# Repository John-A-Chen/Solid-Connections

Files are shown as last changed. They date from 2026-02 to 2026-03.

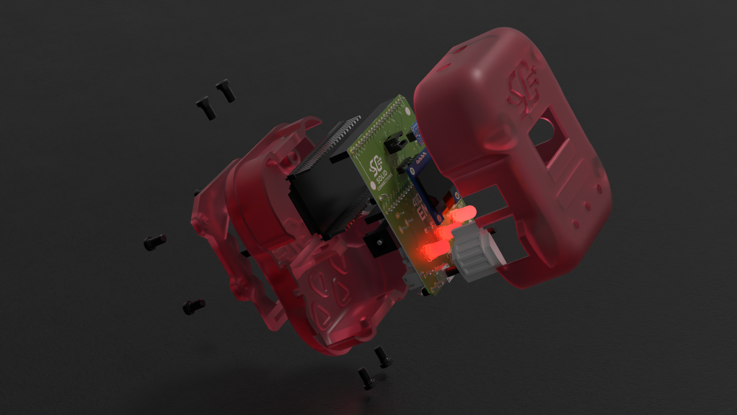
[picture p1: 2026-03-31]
Documentation/Images/render-exploded-assembly-angle-b.png

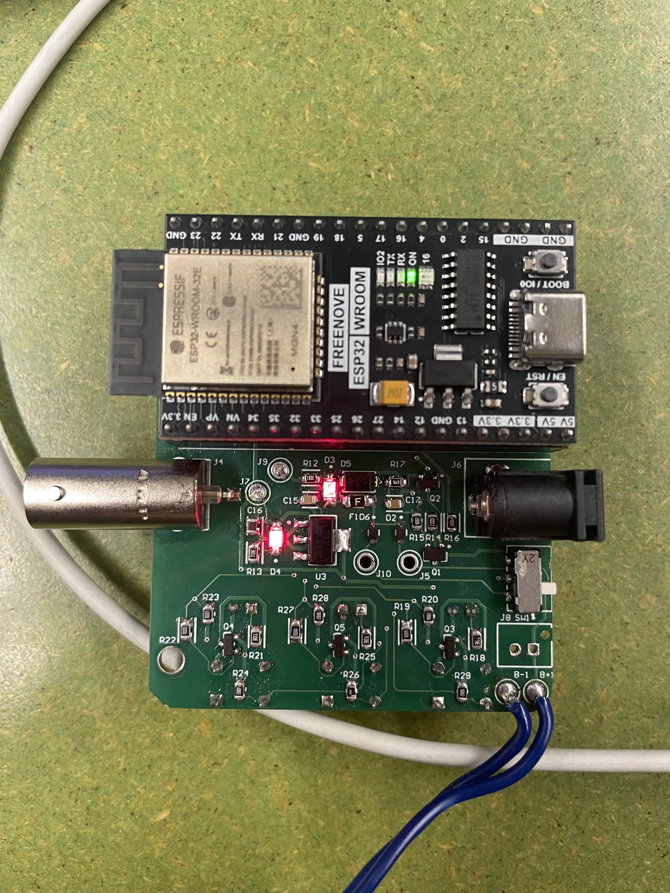
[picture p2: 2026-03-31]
Documentation/Images/photo-pcb-powered-test-setup-01.jpg

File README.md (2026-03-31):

# Solid Connections

Solid Connections is a mechatronics project that combines mechanical CAD, custom PCB design in Altium, and embedded-system prototyping.

## Quick Start (Altium)

1. Open `Electronics/Altium_Project/Solid Connections/Solid Connections.PrjPcb`.
2. Top-level schematic entry: `Electronics/Altium_Project/Solid Connections/Top Level.SchDoc`.
3. Main PCB revisions: `Electronics/Altium_Project/Solid Connections/PBC2A.PcbDoc`, `Electronics/Altium_Project/Solid Connections/PBC2Asave.PcbDoc`, `Electronics/Altium_Project/Solid Connections/PCB2.PcbDoc`.
4. Output job configuration: `Electronics/Altium_Project/Solid Connections/Solid Connections.OutJob`.

## Repository Layout

```text
Solid-Connections/
├── README.md
├── LICENSE
├── CAD/
│   ├── Assemblies/                            # Assembly models (.SLDASM/.STEP)
│   ├── Components/                            # Part models and exports
│   ├── Hardware/                              # Purchased component CAD
│   └── Print_Exports/                         # 3D print outputs (.3mf/.stl)
├── Electronics/
│   ├── Altium_Project/
│   │   └── Solid Connections/                 # Main Altium workspace
│   ├── BOM/                                   # Bill of materials exports
│   └── Reference_Models/                      # PCB/display/MCU reference models
├── Firmware/
│   ├── Archives/                              # Firmware zip bundles
│   └── Vendor/                                # Third-party ESP32 references/examples
├── Documentation/
│   ├── Branding/
│   ├── Diagrams/
│   ├── Reports/
│   └── Images/
├── Assets/
│   └── Fonts/
└── Archive/
    ├── Packages/                              # Legacy packaged iterations
    └── Assets/
```

## Organization Rules

- Put new CAD files in `CAD/` instead of repository root.
- Keep Altium source in `Electronics/Altium_Project/Solid Connections/`.
- Put generated reports/logs under Altium-generated folders (ignored by `.gitignore`).
- Use `Documentation/` for project images/reports and `Archive/` for zip snapshots.

## License

This project is distributed under the license in `LICENSE`.

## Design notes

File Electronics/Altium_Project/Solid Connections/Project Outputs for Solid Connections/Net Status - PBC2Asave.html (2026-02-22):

Altium customize

# Net Status Report

Date: | | 4/06/2025
Time: | | 5:17:29 PM
Elapsed Time: | | 00:00:00
Filename: | | C:\Users\Public\Documents\Altium\Solid Connections\PBC2Asave.PcbDoc
Units: | | mmmils

Nets | Layer | Length
+3V3 | Signal Layers Only | 0mm
+5V | Signal Layers Only | 0mm
0 | Signal Layers Only | 0mm
12 | Signal Layers Only | 40.6737mm
13 | Signal Layers Only | 49.9195mm
14 | Signal Layers Only | 52.9016mm
15 | Signal Layers Only | 0mm
16 | Signal Layers Only | 0mm
17 | Signal Layers Only | 0mm
18 | Signal Layers Only | 0mm
19 | Signal Layers Only | 0mm
2 | Signal Layers Only | 0mm
21 | Signal Layers Only | 25.7781mm
22 | Signal Layers Only | 24.6913mm
23 | Signal Layers Only | 22.0023mm
25 | Signal Layers Only | 42.9603mm
26 | Signal Layers Only | 31.6499mm
27 | Signal Layers Only | 44.5046mm
32 | Signal Layers Only | 14.9368mm
33 | Signal Layers Only | 40.6077mm
34 | Signal Layers Only | 49.115mm
35 | Signal Layers Only | 37.8295mm
4 | Signal Layers Only | 39.3479mm
5 | Signal Layers Only | 0mm
EN | Signal Layers Only | 0mm
GND | Signal Layers Only | 0mm
NetB+1_1 | Signal Layers Only | 36.9959mm
NetC10_1 | Signal Layers Only | 12.2794mm
NetC11_1 | Signal Layers Only | 14.2357mm
NetC14_1 | Signal Layers Only | 14.0683mm
NetC15_1 | Signal Layers Only | 18.5633mm
NetC1_1 | Signal Layers Only | 14.4784mm
NetC5_1 | Signal Layers Only | 9.7431mm
NetC6_1 | Signal Layers Only | 8.6443mm
NetD1_1 | Signal Layers Only | 2.8287mm
NetD2_1 | Signal Layers Only | 6.9889mm
NetD2_2 | Signal Layers Only | 22.8815mm
NetD3_1 | Signal Layers Only | 2.0752mm
NetD4_1 | Signal Layers Only | 3.4106mm
NetD6_2 | Signal Layers Only | 25.097mm
NetD7_1 | Signal Layers Only | 3.2374mm
NetD8_1 | Signal Layers Only | 3.2374mm
NetD9_1 | Signal Layers Only | 3.2374mm
NetJ6_1 | Signal Layers Only | 13.8037mm
NetQ1_1 | Signal Layers Only | 10.1075mm
NetQ1_2 | Signal Layers Only | 3.3561mm
NetQ2_1 | Signal Layers Only | 8.0976mm
NetQ3_1 | Signal Layers Only | 11.5765mm
NetQ3_3 | Signal Layers Only | 17.3859mm
NetQ4_1 | Signal Layers Only | 11.5693mm
NetQ4_3 | Signal Layers Only | 17.3053mm
NetQ5_1 | Signal Layers Only | 11.5725mm
NetQ5_3 | Signal Layers Only | 17.1924mm
NetR10_1 | Signal Layers Only | 4.1393mm
NetR2_2 | Signal Layers Only | 6.6042mm
NetR3_1 | Signal Layers Only | 4.6455mm
NetR6_2 | Signal Layers Only | 6.6438mm
NetR8_1 | Signal Layers Only | 3.8342mm
NetU1_13 | Signal Layers Only | 1.27mm
NetU1_8 | Signal Layers Only | 1.27mm
RX | Signal Layers Only | 0mm
TX | Signal Layers Only | 0mm
VN | Signal Layers Only | 0mm
VP | Signal Layers Only | 0mm
X | Signal Layers Only | 23.7791mm
Y | Signal Layers Only | 21.3639mm
Z | Signal Layers Only | 20.3039mm

Back to top

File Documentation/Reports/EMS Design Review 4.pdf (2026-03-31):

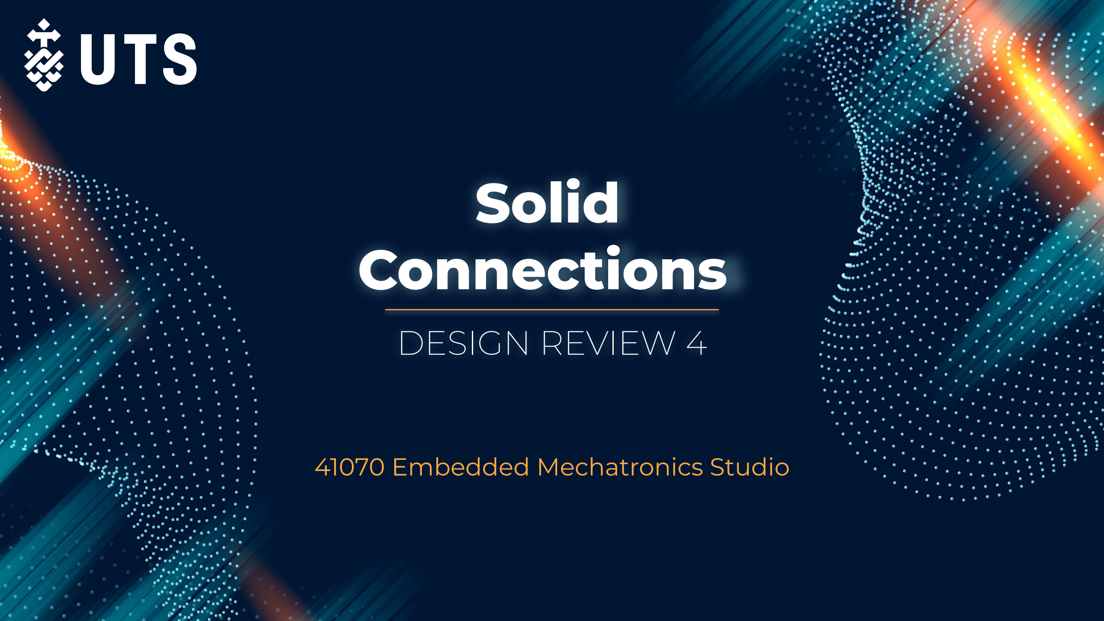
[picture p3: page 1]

# Solid Connections

## 41070 Embedded Mechatronics Studio

# DESIGN REVIEW 4

# Team Introduction [Lab 2 Group 4]

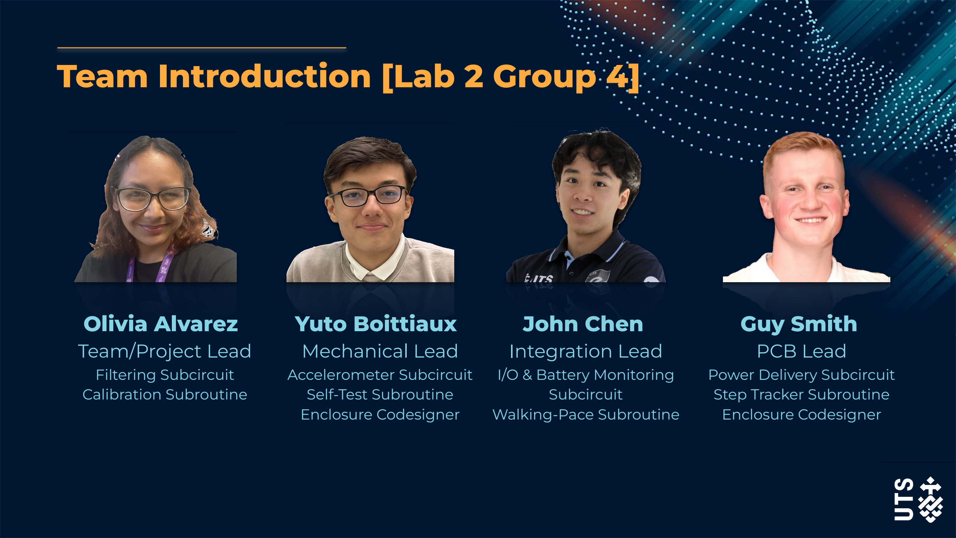
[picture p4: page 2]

## Guy Smith

## PCB Lead

Power Delivery Subcircuit
Step Tracker Subroutine
Enclosure Codesigner

## Yuto Boittiaux

## Mechanical Lead

Accelerometer Subcircuit
Self-Test Subroutine
Enclosure Codesigner

## John Chen

## Integration Lead

I/O & Battery Monitoring
Subcircuit
Walking-Pace Subroutine

## Olivia Alvarez

## Team/Project Lead

Filtering Subcircuit
Calibration Subroutine

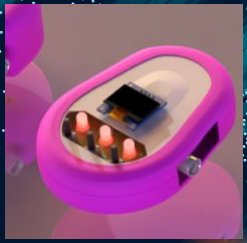
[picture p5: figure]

# Step Tracker: System and Application Overview

## Purpose

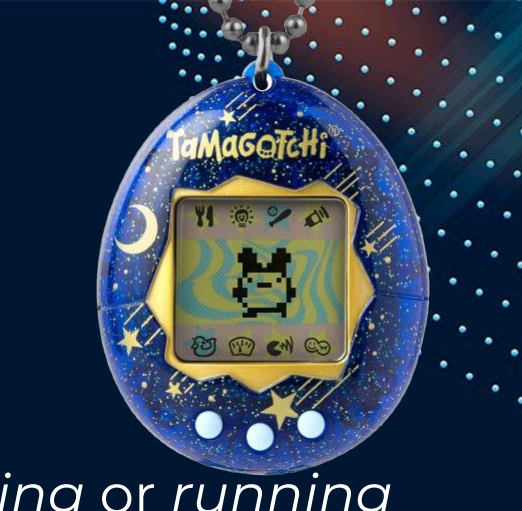
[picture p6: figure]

## - To detect whether the user is stationary, walking or running - Track the number of steps the user has taken - Be an ergonomic and easy to use step tracker

## System Parts - ESP32 integrated with a custom PCB - Accelerometer for movement tracking - Mechanical enclosure imitating a tamagotchi for interactive user experience

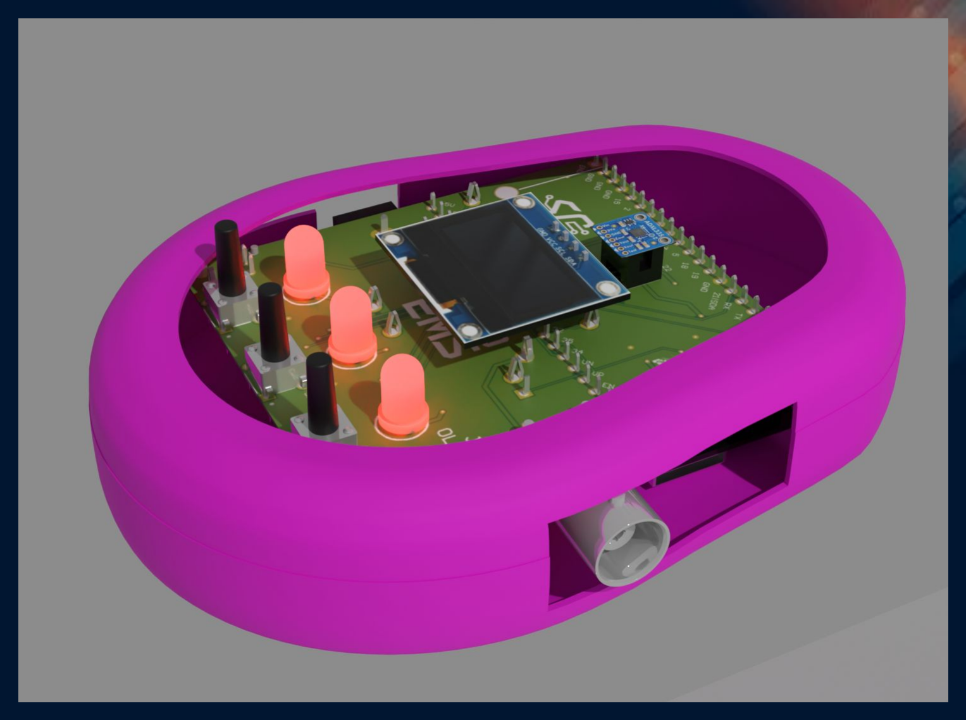
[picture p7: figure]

## - User interface to indicate step count and allow control of software modes

## Contract

Project expectations | Communication and Collaboration

## 1. Attendance & Participation 2. Communication 3. Collaboration 4. Project Timeline 5. Task Tracking 6. Financial Contributions

## Primary Communication: Discord Collaboration: Google Drive Response Expectations: 24 hours Task Tracking: Gantt Chart

# Project Plan / Gantt Chart

# System

# Overview and Specifications

# Functional and Hardware Requirements

Subsystem | Details
Power | 2S LiPo (7.2 V) + external lab PSU via DC barrel jack. Charging circuit + 3.3 V LDO regulator. Voltage divider to ESP32 ADC. System switch and power indicator LEDs.
Sensor | ADXL335 with analog output (3.3 V), ST pin toggled via GPIO. Analog low-pass filtering on X, Y, Z axes.
I/O | Minitek127 headers, test points for power/filtering signals, BNC connector for Z-axis debug output.
User Interface | 3x push buttons: Mode, Reset, Calibrate. 3x pace LEDs. OLED (128×64, I2C).
Microcontroller | ESP32 dev board handles acquisition, pace detection, calibration, display, and control.
Mechanical Enclosure | Tamagotchi-style housing with cutouts for I/O, wearable attachment, and mounting interface.

# Project Evolution

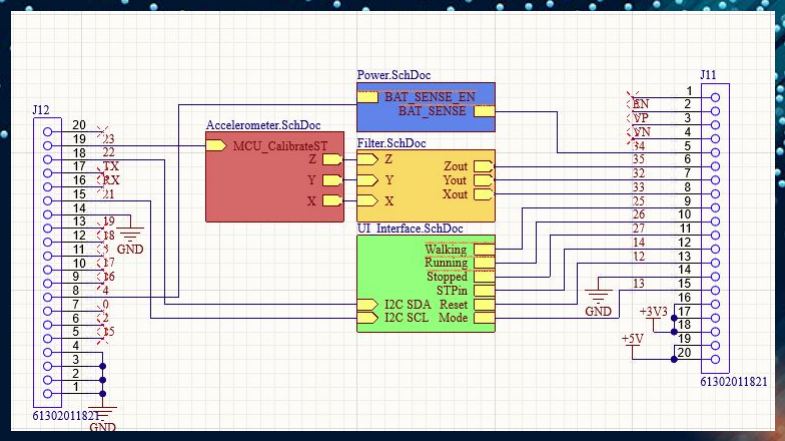
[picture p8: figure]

Aspect | Design 1 | Design 2 | Design 3
Microcontroller | Arduino Uno/Nano | ESP32 | ESP32
Power Supply | 9V Battery | 2 Lithium-Ion cells in series | 2 Lithium-Ion cells in series
PCB Layers | Single-layer | Dual-layer | Dual-layer
Signal Conditioning | Basic second-order filter | Sallen-key second order filter with absence of buffer amplifier | Sallen-key second-order filter with buffer amplifier
User Interface | Not considered | Inclusion of Buttons and OLED | Full Implementation of buttons, OLED and LEDs
Connection Accuracy | Convoluted connections and no microcontroller integration | Incorrect ADXL assignments and pin headers | Correct ADXL connection and ESP32 pin alignment
Mechanical | Simple box casing | Tamagotchi-style concept ideated | Tamagotchi-style refined and made more ergonomic

# Finalised Concept

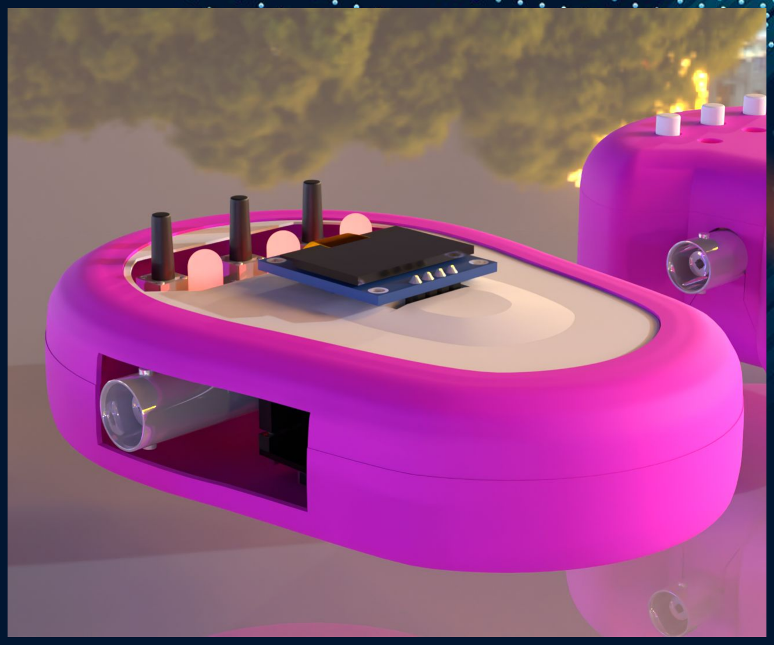
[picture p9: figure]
Insert moving model of final design here (if finished by presentation)

# - ESP32 Microcontroller - 7.6 LiPo Battery - Sallen-Key second-order low-pass filter - Tamagotchi style ergonomic mechanical enclosure - OLED screen compatible with mechanical casing - 3 buttons and 3 LEDs for better user experience

# Block Diagram

## Guy Smith

Key | Descriptor
| PCB
| ESP32
| Software
| User experience
| Power

# PCB

# Innovation and Creativity

# Innovative PCB features

# Double sided

# - Thru-hole on top, smd on bottom

# Attention to detail

- All components placed using coordinates, not snaps.

# Beveled edges - Safety in mind, cannot be used as a box cutter

# Low voltage protection - Turns off instead of draining batteries too low

# Creative Design: Accelerometer

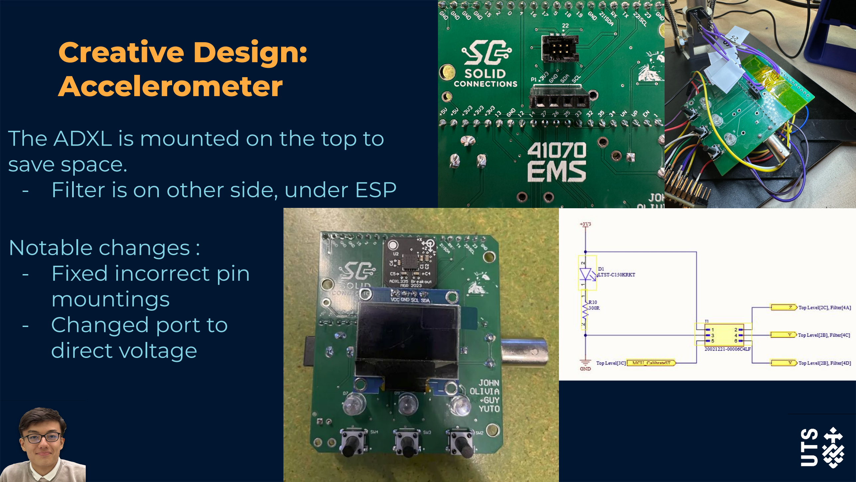
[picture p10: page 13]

# Notable changes : - Fixed incorrect pin mountings - Changed port to direct voltage

# The ADXL is mounted on the top to

save space.

# - Filter is on other side, under ESP

# User Experience

# Buttons on bottom

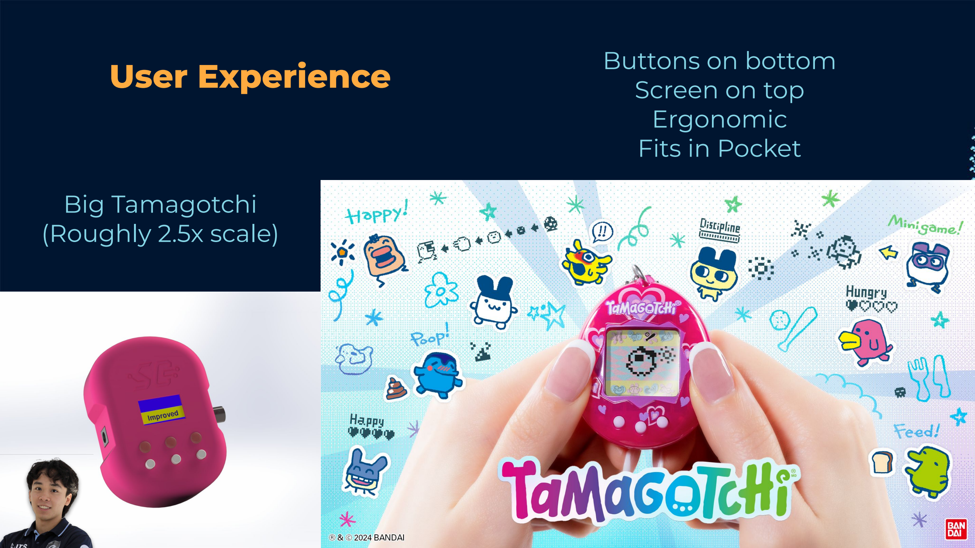
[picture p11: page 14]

# Big Tamagotchi (Roughly 2.5x scale)

# Screen on top Ergonomic Fits in Pocket

# Power Schematic:

# - Charging circuit is up in the air

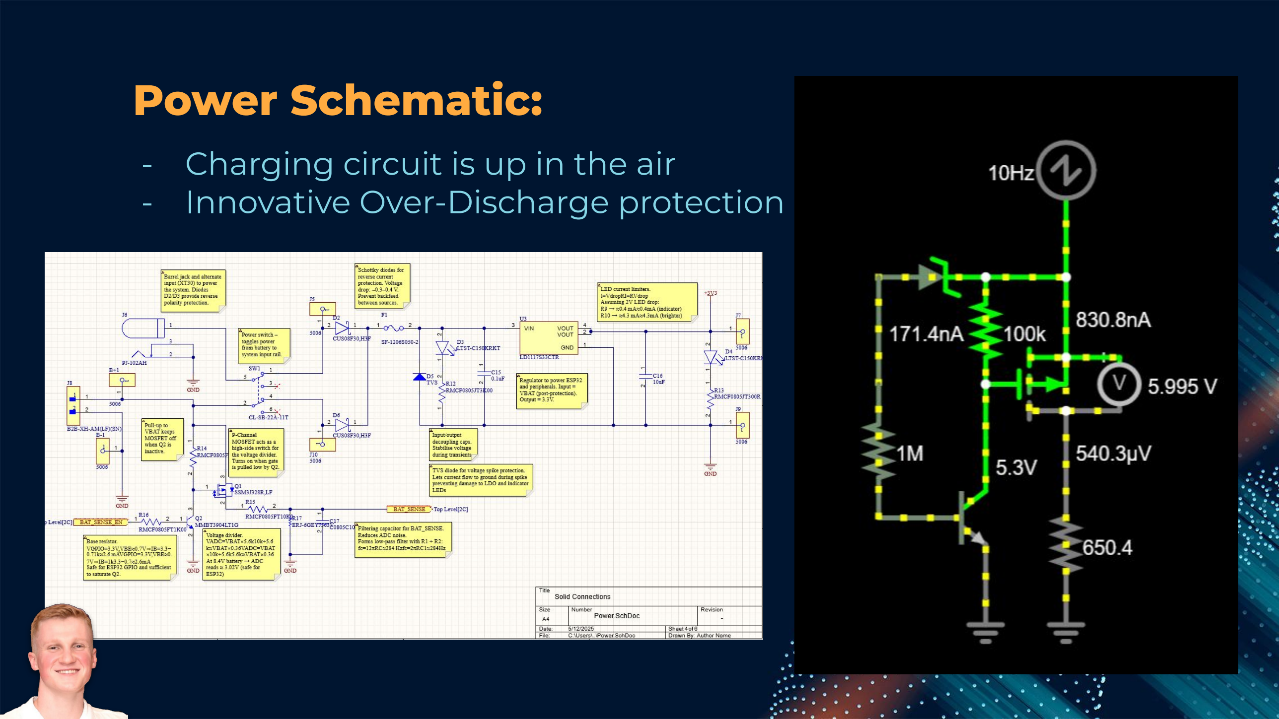
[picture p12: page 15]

# - Innovative Over-Discharge protection

# Analog Filter - Schematic

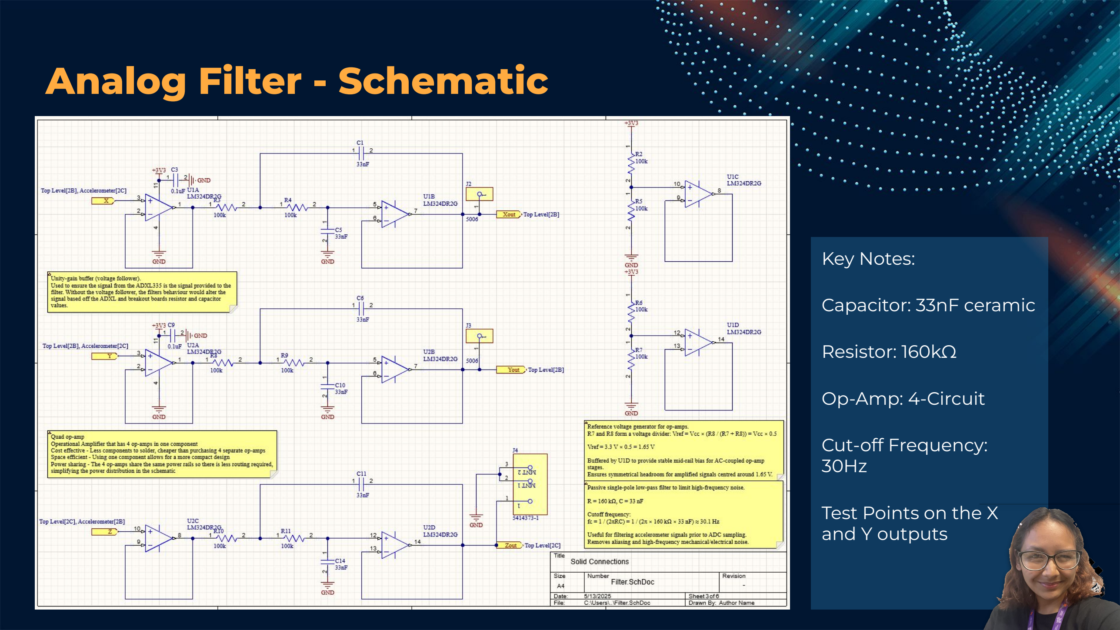
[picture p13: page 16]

Key Notes:

Capacitor: 33nF ceramic

Resistor: 160kΩ

Op-Amp: 4-Circuit

Cut-off Frequency:
30Hz

Test Points on the X
and Y outputs

# Analog Filter - Mathematics

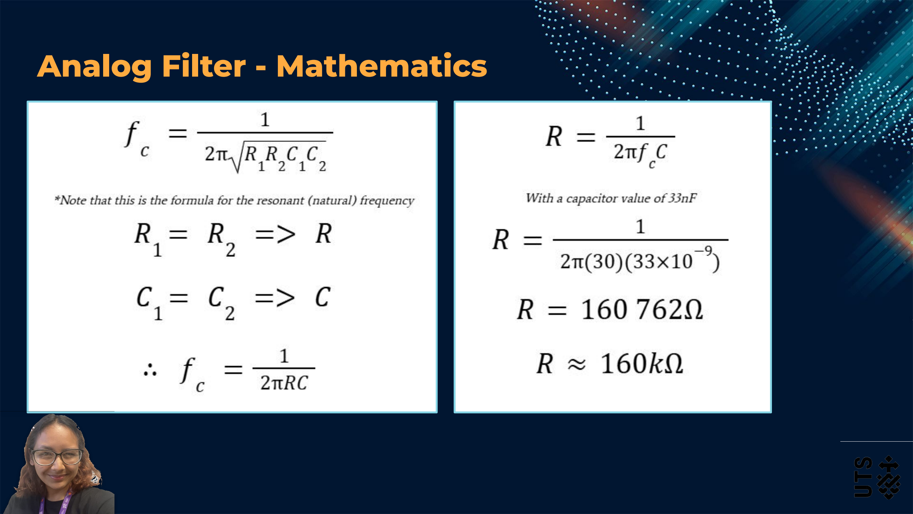
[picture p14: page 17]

# Analog Filter - Simulation vs Tested Data

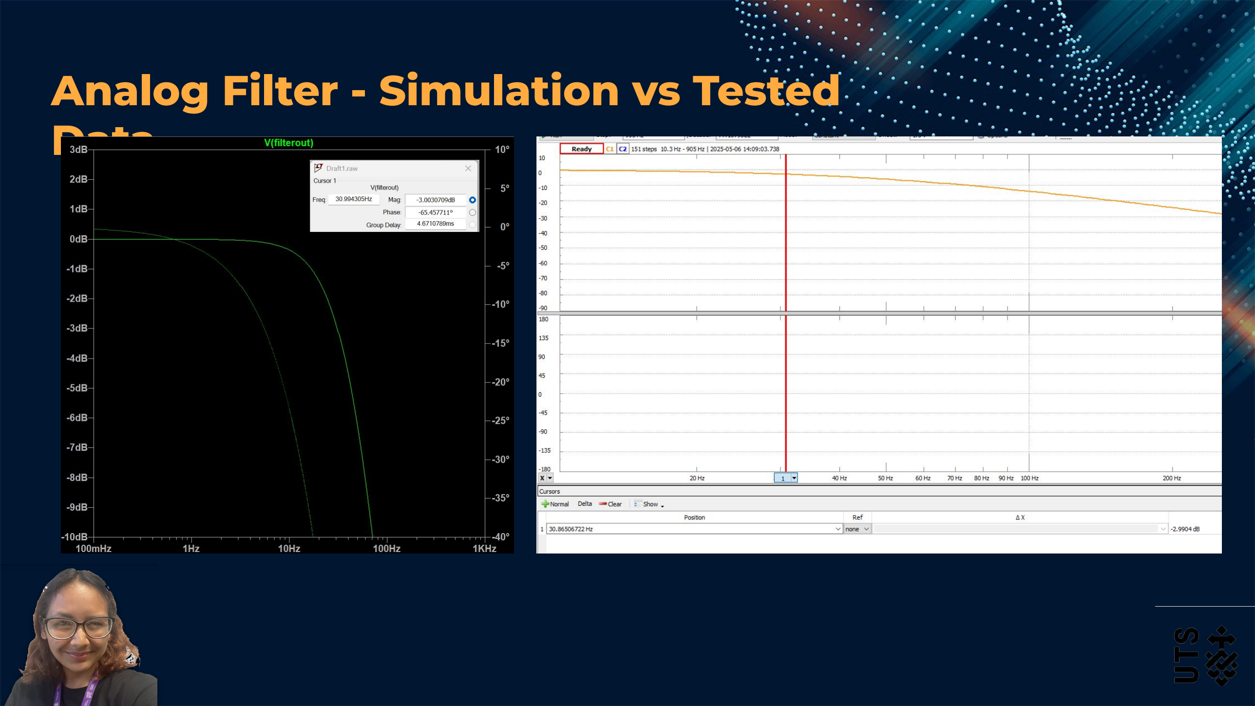
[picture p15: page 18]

# System Peripherals

Changed to 0.96” OLED

Implemented Buttons

Added State LEDS

Added Comments

# Signal Mapping Table

# BOM

# Enclosure

# Innovation and Creativity

# Enclosure Design

# Prototype 1

### Design Requirements :

### Sturdy enclosure to house the PCB stack with appropriate use of

fasteners.

### Appropriately sized cut-outs for

peripherals (LEDs, buttons,

### switches, LCD) and cable

connections.

### Provide means to attach the enclosure to your body to

demonstrate the step tracker.

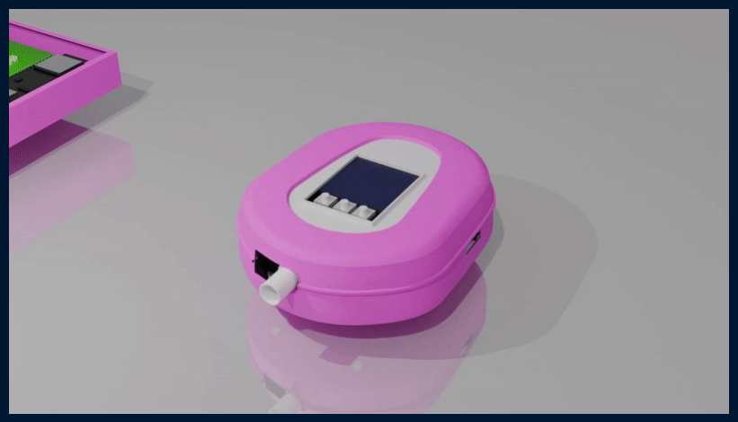
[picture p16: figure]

### Provide a mounting interface for the experimental demonstration and test setup. Drawing provided

below.

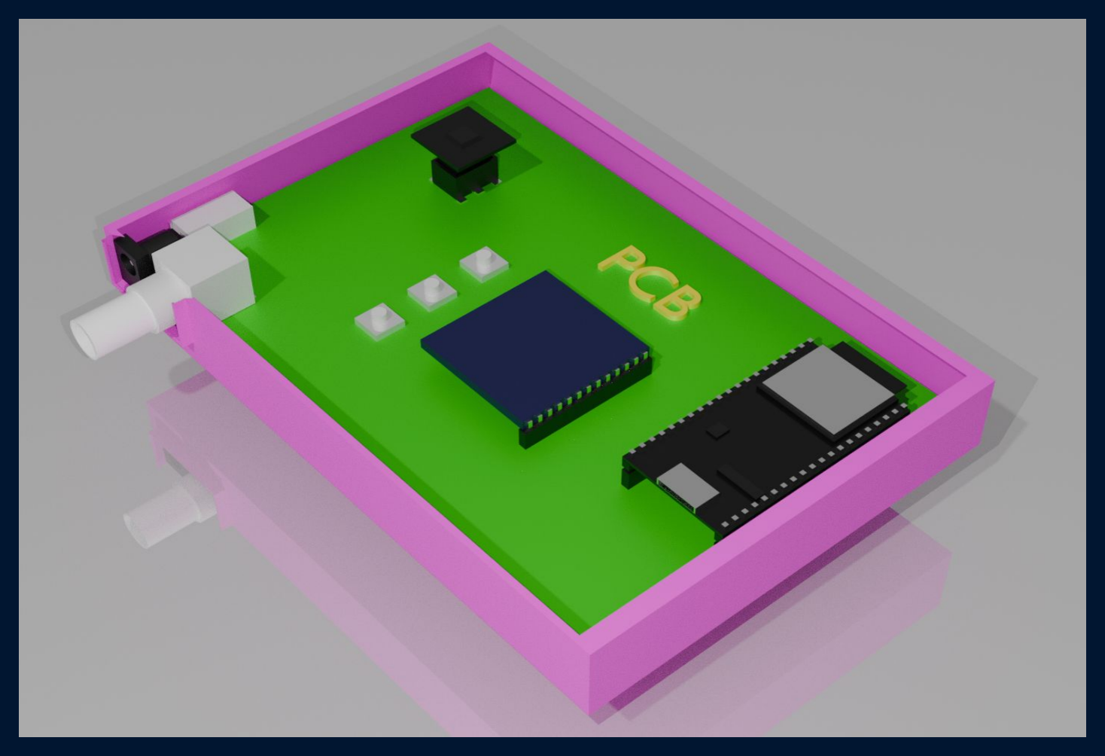
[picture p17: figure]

# Prototype 2

# Enclosure Design Evolution

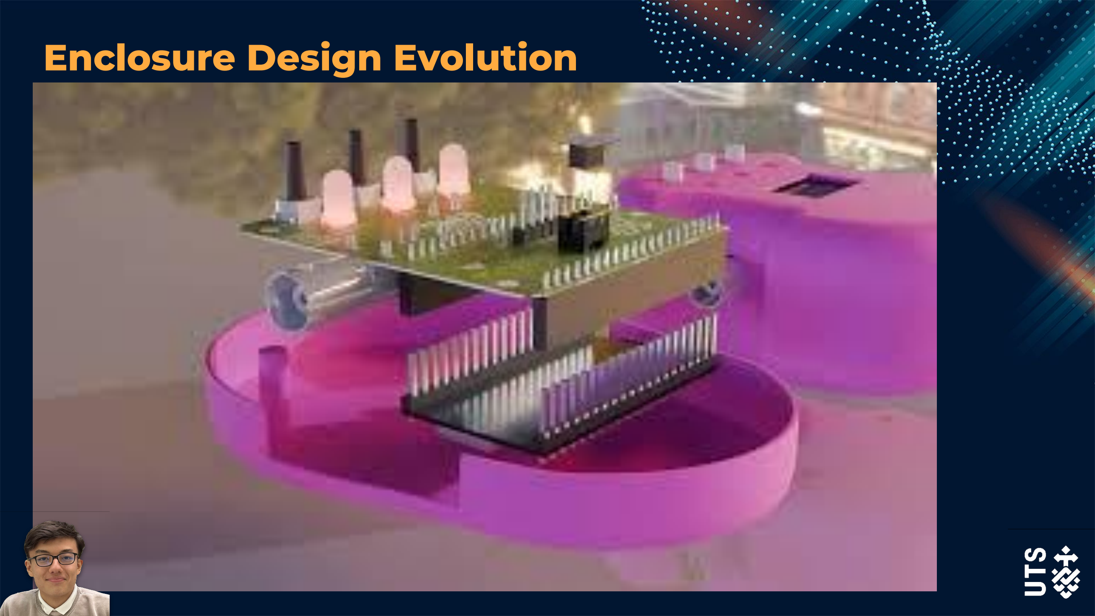
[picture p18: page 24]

# Enclosure Design

# Prototype 3

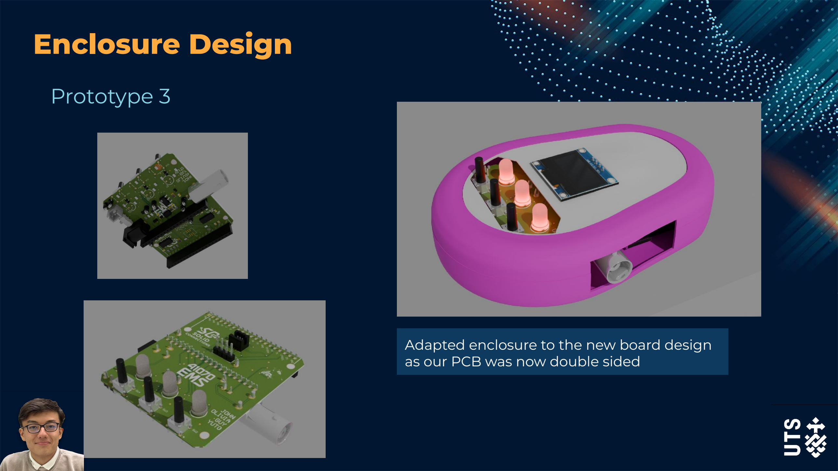
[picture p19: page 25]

### Adapted enclosure to the new board design as our PCB was now double sided

# Enclosure Design

# Prototype 4

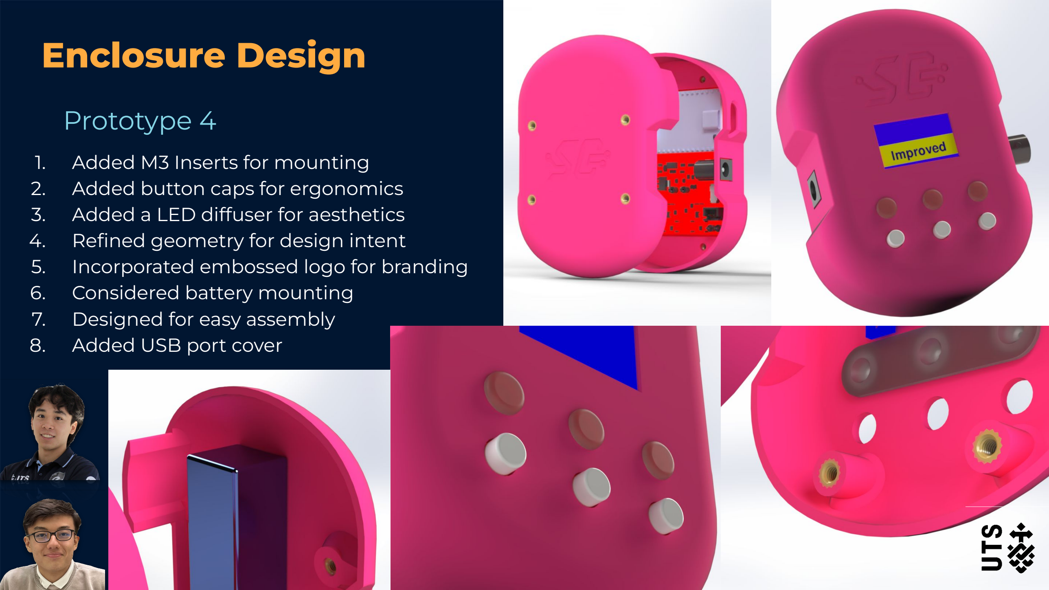
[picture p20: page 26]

## 1. Added M3 Inserts for mounting 2. Added button caps for ergonomics 3. Added a LED diffuser for aesthetics 4. Refined geometry for design intent 5. Incorporated embossed logo for branding 6. Considered battery mounting 7. Designed for easy assembly 8. Added USB port cover

# Embedded

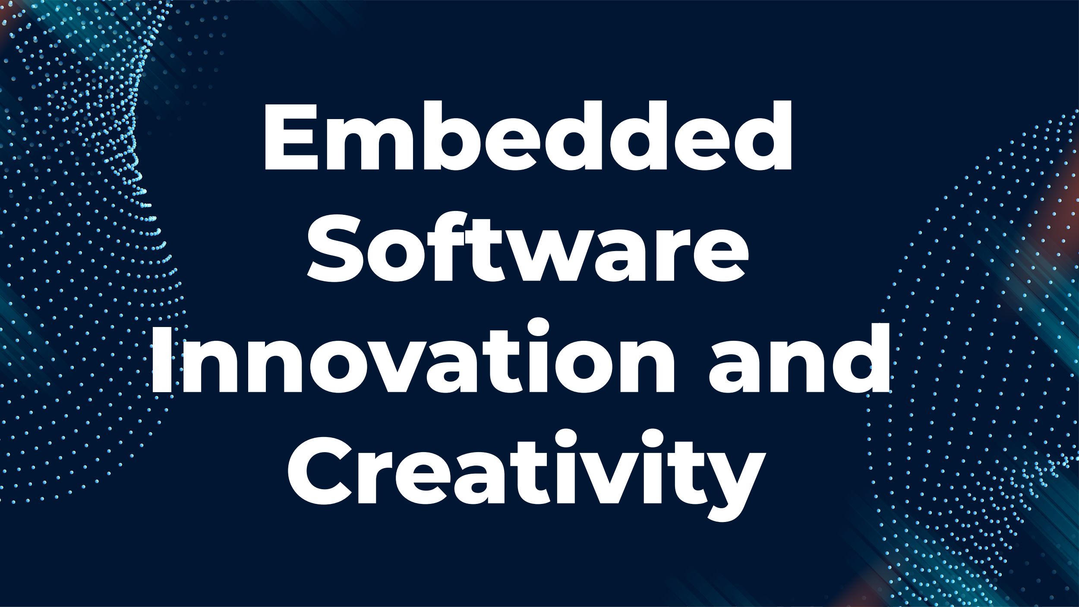
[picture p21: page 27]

# Software Innovation and Creativity

# Flowchart of Step Tracker

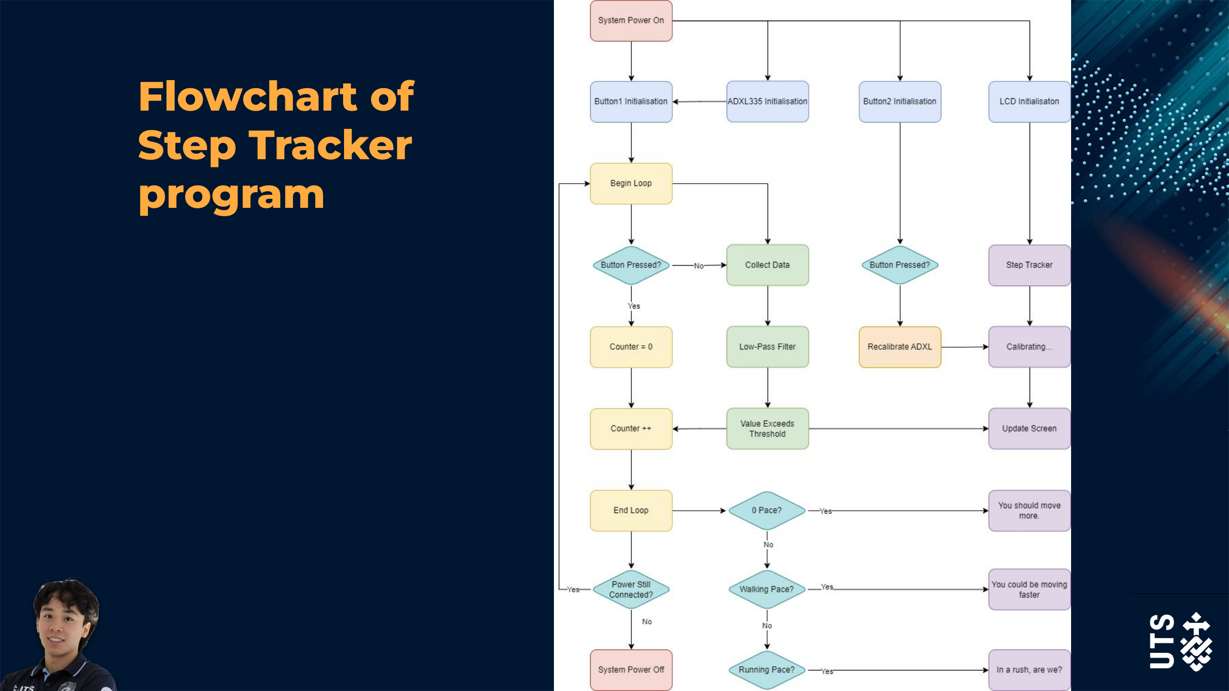
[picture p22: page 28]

# program

# Self-test routine

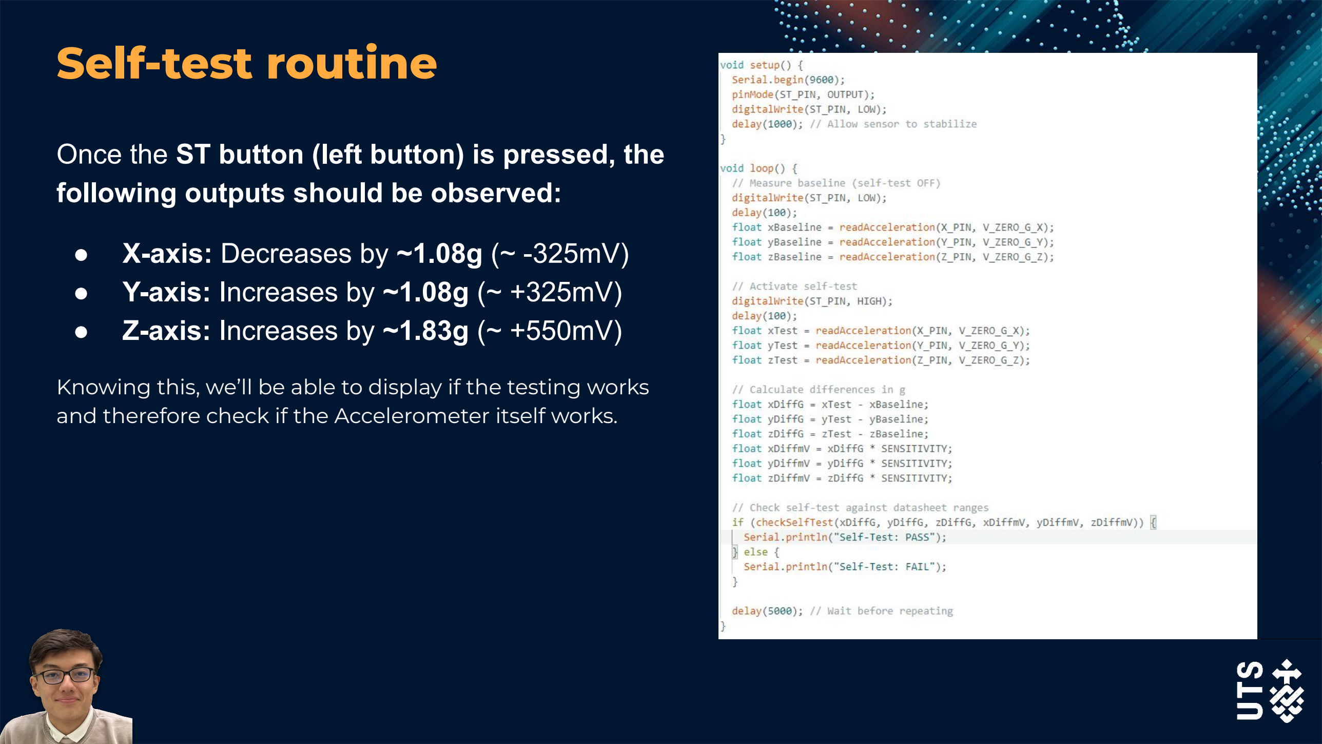
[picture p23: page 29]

Once the ST button (left button) is pressed, the following outputs should be observed:

- X-axis: Decreases by ~1.08g (~ -325mV)
- Y-axis: Increases by ~1.08g (~ +325mV)
- Z-axis: Increases by ~1.83g (~ +550mV)

Knowing this, we’ll be able to display if the testing works and therefore check if the Accelerometer itself works.

## - Starts when user presses the

# Calibration routine

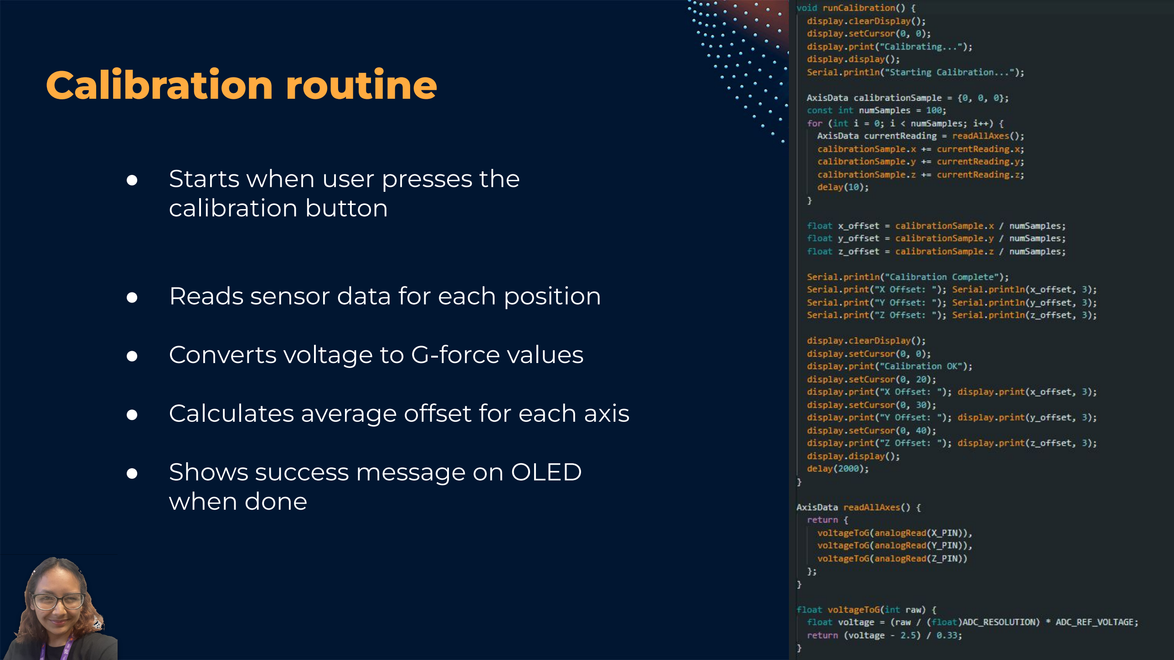
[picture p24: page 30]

## calibration button

## - Reads sensor data for each position

## - Converts voltage to G-force values

## - Calculates average offset for each axis

## - Shows success message on OLED when done

# Step tracker routine

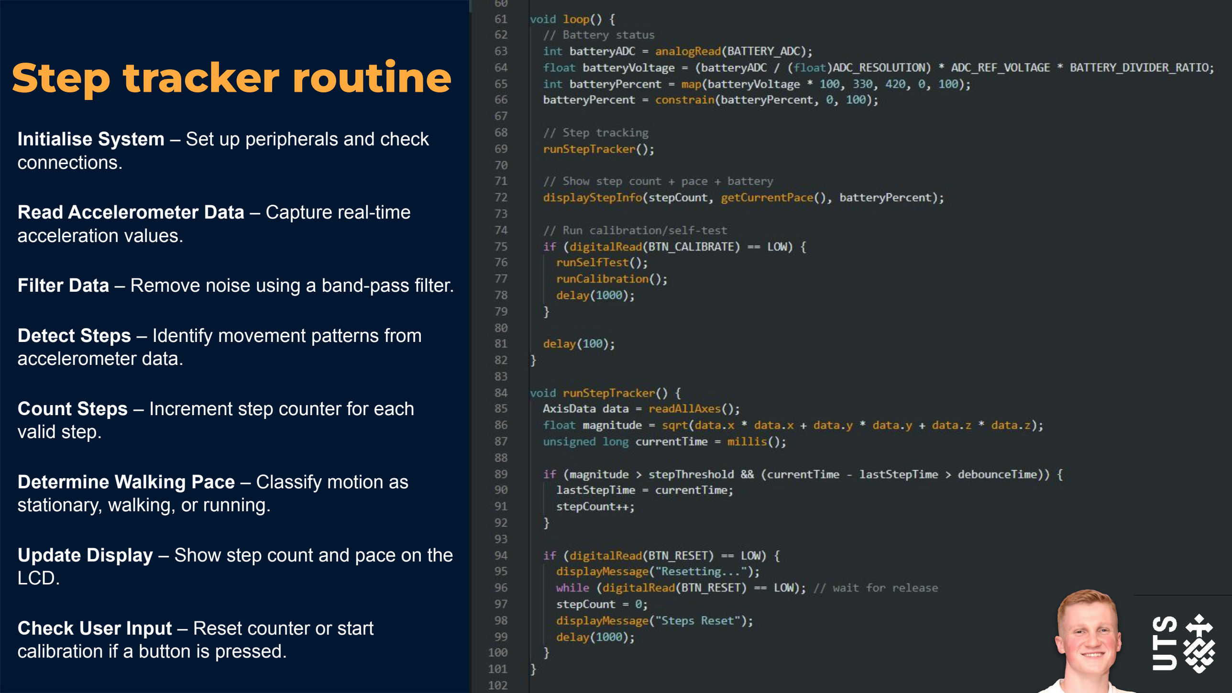
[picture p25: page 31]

Initialise System – Set up peripherals and check connections.

Read Accelerometer Data – Capture real-time acceleration values.

Filter Data – Remove noise using a band-pass filter.

Detect Steps – Identify movement patterns from accelerometer data.

Count Steps – Increment step counter for each valid step.

Determine Walking Pace – Classify motion as stationary, walking, or running.

Update Display – Show step count and pace on the LCD.

Check User Input – Reset counter or start calibration if a button is pressed.

# Walking-pace identification routine

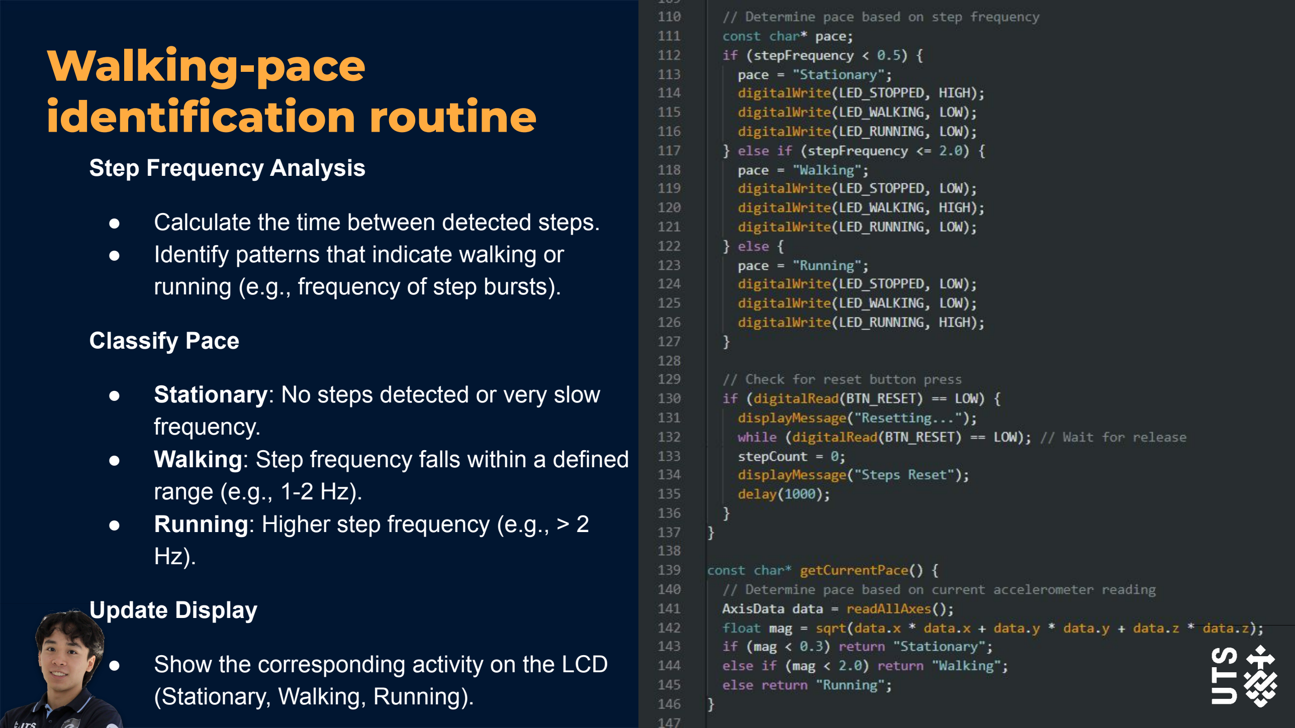
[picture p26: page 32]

Step Frequency Analysis

- Calculate the time between detected steps.
- Identify patterns that indicate walking or running (e.g., frequency of step bursts).

Classify Pace

- Stationary: No steps detected or very slow frequency.
- Walking: Step frequency falls within a defined range (e.g., 1-2 Hz).
- Running: Higher step frequency (e.g., > 2 Hz).

Update Display

- Show the corresponding activity on the LCD (Stationary, Walking, Running).

Evaluation,

# feedback & reflection

# Group Self-Evaluation

Expert | Proficient | Developing | Novice

## Overall Delivery and Presentation

## Team Profile, Collaboration & Communication

## System Overview

## Project Management

# Incorporation of improvement following feedback

Q&A

## Thank you for joining us today!

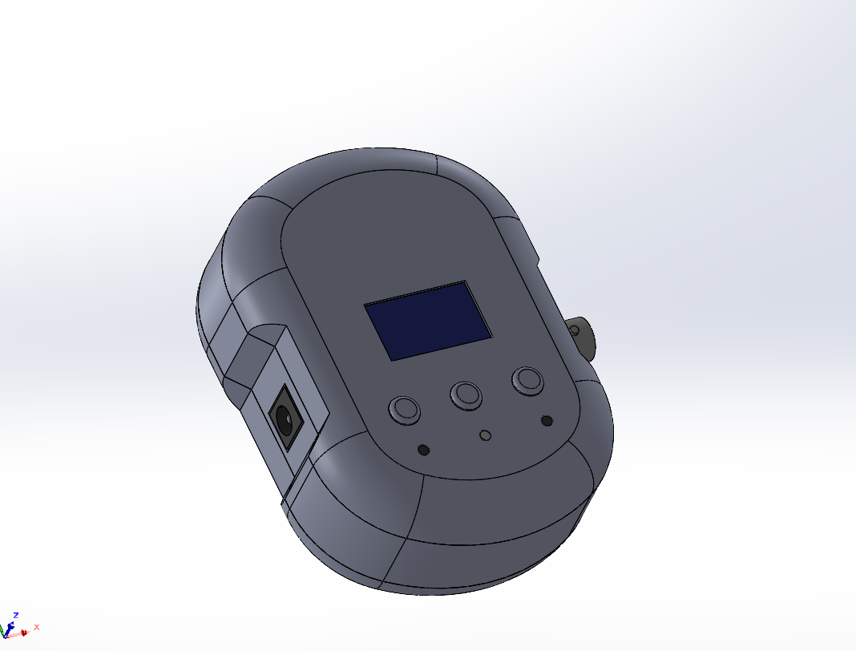
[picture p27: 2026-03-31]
Documentation/Images/cad-enclosure-concept-angle-02.png

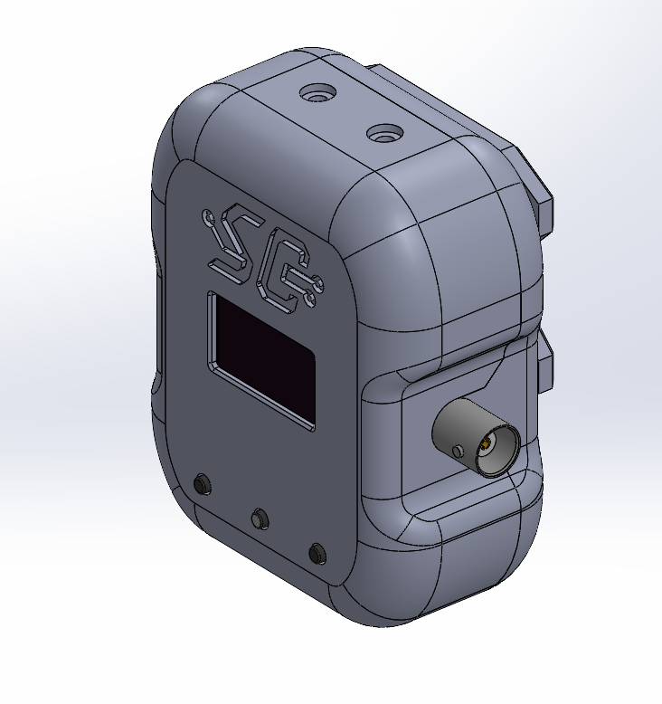
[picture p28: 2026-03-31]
Documentation/Images/cad-enclosure-concept-angle-01.png

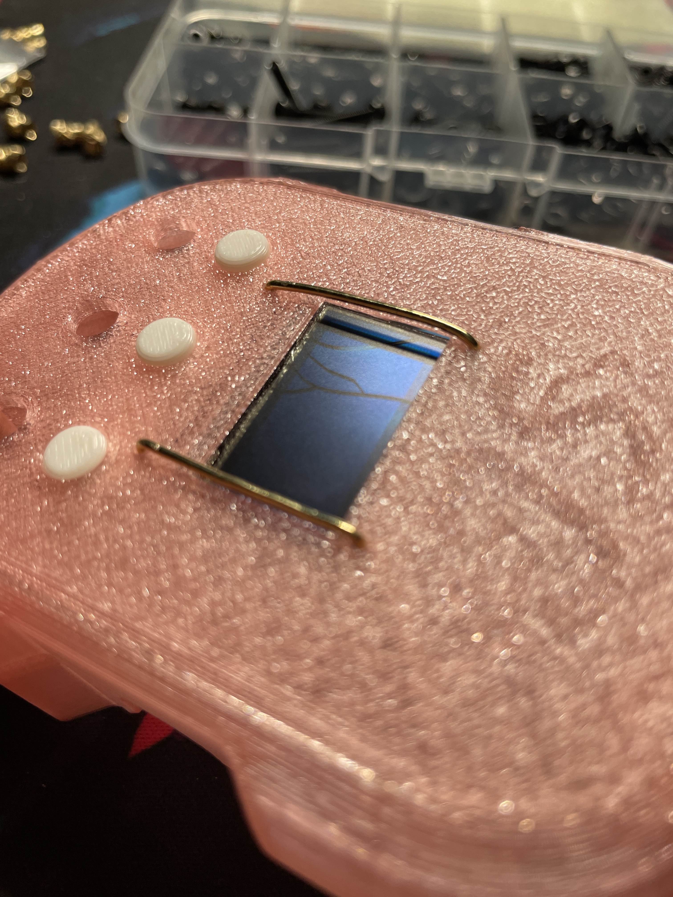
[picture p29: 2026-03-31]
Documentation/Images/photo-enclosure-front-cutout-closeup.jpg

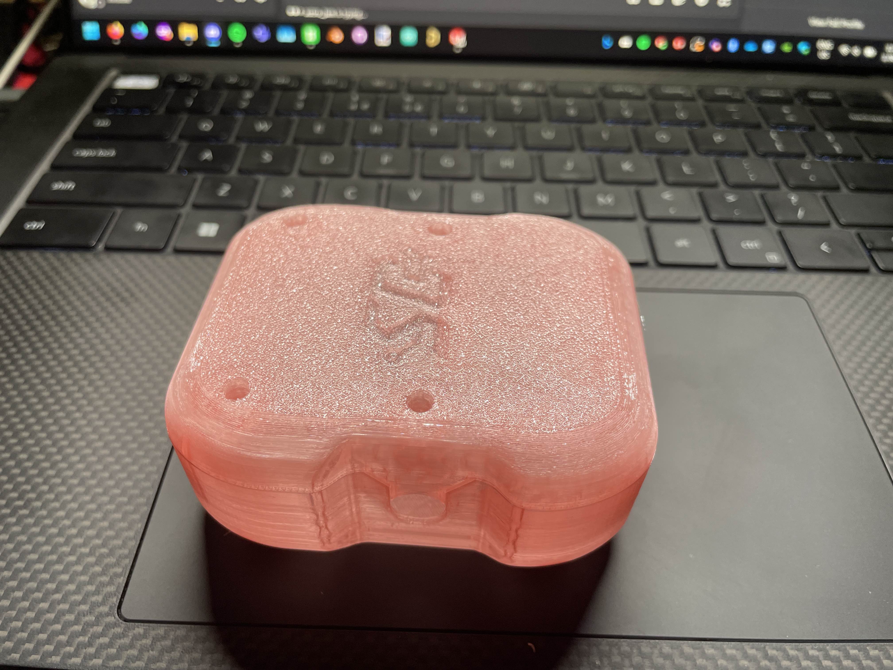
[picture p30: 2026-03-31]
Documentation/Images/photo-enclosure-rear-view-01.jpg

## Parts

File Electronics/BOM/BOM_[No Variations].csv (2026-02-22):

Line # | Name | Description | Designator | Revision ID | Revision Status | Quantity | Manufacturer 1 | Manufacturer Part Number 1 | Manufacturer Lifecycle 1 | Supplier 1 | Supplier Part Number 1 | Supplier Unit Price 1 | Supplier Subtotal 1
17 | 5006 | PC TEST POINT COMPACT BLACK | B-1, B+1, J2, J3, J5, J7, J9, J10 | CMP-19636-000022-1 | Up to date | 8 | Keystone Electronics | 5006 | Volume Production | Digikey | 36-5006-ND | 0.40673 | 16.26934
9 | 0.1uF | CAP CER 0.1UF 50V X7R 0805 | C3, C9, C15 | CMP-03020-000950-1 | Up to date | 3 | KEMET | C0805C104J5RACTU | Volume Production | Digikey | 399-C0805C104J5RACTUDKR-ND | 0.1302 | 1.95306
10 | CUS08F30,H3F | CUS08F30,H3F Rectifier Diode, Schottky, 1 Phase, 1 Element, 0.8A, 30V V(RRM), Silicon | D2, D6 | CMP-00375-53632863-1 | Up to date | 2 | Toshiba | CUS08F30,H3F | Volume Production | Digikey | CUS08F30H3FCT-ND | 0.22941 | 2.29408
16 | 61302011821 |  | J11, J12 | CMP-1502-01348-3 | Up to date | 2 | Wurth Electronics | 61302011821 | Volume Production | Digikey | 732-61302011821-ND | 1.28654 | 12.86542
3 | 61300411121 |  | P1 | CMP-1502-01064-3 | Up to date | 1 | Wurth Electronics | 61300411121 | Volume Production | Digikey | 732-5317-ND | 0.26351 | 1.31754
11 | DMN2004K-7 | MOSFET N-CH 20V 0.63A SOT23-3 | Q3, Q4, Q5 | CMP-12801-000057-1 | Up to date | 3 | Diodes | DMN2004K-7 | Volume Production | Digikey | DMN2004KDICT-ND | 0.29606 | 4.4409
24 | SSM3J328R,LF | TOSHIBA Field-Effect Transistor Silicon P-Channel MOS Type (U-MOS VI), 20 V, -55 to 125 degC, 3-Pin SOTFL, RoHS, Tape and Reel | Q1 | CMP-2100-03686-1 | Up to date | 1 | Toshiba | SSM3J328R,LF | Volume Production | Digikey | SSM3J328RLFCT-ND | 0.65102 | 3.25511
22 | MMBT3904LT1G | General Purpose Transistor, NPN Silicon, 3-Pin SOT-23, Pb-Free, Tape and Reel | Q2 | CMP-1048-00631-1 | Up to date | 1 | ON Semiconductor | MMBT3904LT1G | Volume Production | Digikey | MMBT3904LT1GOSCT-ND | 0.18601 | 0.93003
13 | RMCF0805JT3K00 | 3kΩ ±5% 0.125W 0805 Thick Film Chip Resistor AEC-Q200 compliant | R12 | CMP-26527-006913-1 | Up to date | 1 | Stackpole Electronics | RMCF0805JT3K00 | Volume Production | Digikey | RMCF0805JT3K00CT-ND | 0.0341 | 0.34101
19 | CL-SB-22A-11T | SWITCH SLIDE DPDT 200MA 12V | SW1 | CMP-71745-000011-1 | Up to date | 1 | Nidec Copal | CL-SB-22A-11T | Unknown | Digikey | 563-1340-1-ND | 2.23207 | 11.16037
8 | LM324DR2G | Single Supply Quad Operational Amplifier, 3 to 32 V, 0 to 70 degC, 14-Pin SOIC, Pb-Free, Tape and Reel | U1, U2 | CMP-1310-00171-1 | Up to date | 2 | ON Semiconductor | LM324DR2G | Volume Production | Digikey | LM324DR2GOSCT-ND | 0.30536 | 3.0536
7 | LD1117S33CTR | IC REG LINEAR 3.3V 800MA SOT223 | U3 | CMP-0244-00307-2 | Up to date | 1 | STMicroelectronics | LD1117S33CTR | Volume Production | Digikey | 497-1241-1-ND | 0.49602 | 2.48008
14 | 300Ω, RMCF0805JT300R | 300Ω ±5% 0.125W 0805 Thick Film Chip Resistor AEC-Q200 compliant, RMCF0805JT300R | R1, R13, R18, R21, R25 | CMP-26527-003681-1 | Up to date | 5 | Stackpole Electronics | RMCF0805JT300R | Volume Production | Digikey | 738-RMCF0805JT300RCT-ND | 0.0341 | 0.85253
 | 10k, RMCF0805FT10K0 | RES 10K OHM 1% 1/8W 0805, RMCF0805FT10K0 | R15, R20, R23, R24, R26, R28, R29 | CMP-26527-000121-1 | Up to date | 7 | Stackpole Electronics | RMCF0805FT10K0 | Volume Production | Digikey | RMCF0805FT10K0CT-ND | 0.03875 | 1.35629
 | RMCF0805FG100K, 100k | 100kΩ ±1% 0.125W 0805 Thick Film Chip Resistor AEC-Q200 compliant | R2, R3, R4, R5, R6, R7, R8, R9, R10, R11, R14 | CMP-26527-003818-1 | Up to date | 11 | Stackpole Electronics | RMCF0805FG100K | Volume Production | Digikey | RMCF0805FG100KCT-ND | 0.0186 | 1.86006
 | RMCF0805FT1K00 | 1kΩ ±1% 0.125W 0805 Thick Film Chip Resistor AEC-Q200 compliant | R16 | CMP-26527-002331-1 | Up to date | 1 | Stackpole Electronics | RMCF0805FT1K00 | Volume Production | Digikey | RMCF0805FT1K00CT-ND | 0.03875 | 0.38751
 | 100Ω | 100Ω ±1% 0.125W 0805 Thick Film Chip Resistor AEC-Q200 compliant, RMCF0805FT100R | R19, R22, R27 | CMP-26527-001731-1 | Up to date | 3 | Stackpole Electronics | RMCF0805FT100R | Volume Production | Digikey | RMCF0805FT100RCT-ND | 0.03875 | 0.58127
 | 33nF | CAP CER 0.033UF 50V X7R 0805, CC0805KRX7R9BB333 | C1, C5, C6, C10, C11, C14 | CMP-03422-000099-1 | Up to date | 6 | Yageo | CC0805KRX7R9BB333 | Volume Production | Digikey | 311-1374-1-ND | 0.09145 | 2.74359
 | LTST-C150KRKT | LED RED CLEAR 1206 SMD | D1, D3, D4 | CMP-2000-06617-2 | Up to date | 3 | Vishay Lite-On | LTST-C150KRKT | Volume Production | Digikey | 160-1405-1-ND | 0.19376 | 2.90635
 | C0805C103J5RAC7210 | CAP CER SMD 0805 .01UF X7R 5% 50 | C17 | CMP-2007-01173-3 | Up to date | 1 | KEMET | C0805C103J5RAC7210 | Volume Production | Digikey | 399-17616-1-ND | 0.06975 | 0.69752
 | PJ-102AH | Power Barrel Con, 2.0mm ID, 5.5mm OD, 5A | J6 |  |  | 1 | Same Sky | PJ-102AH | Unknown | Digikey | CP-102AH-ND | 1.17804 | 5.89019
 | 20021221-00006C4LF |  | J1 |  |  | 1 | Amphenol ICC / FCI | 20021221-00006C4LF | Unknown | Digikey | 609-3699-1-ND | 1.10054 | 5.50268
 | 10uF | CAP CER 10UF 10V X7R 0805 | C16 | CMP-03020-034708-1 | Up to date | 1 | KEMET | C0805C106J8RACAUTO | Unknown | Digikey | 399-15693-1-ND | 1.36404 | 6.82022
 | TVS | Transient Voltage Suppressor, 6.40 to 231 V, 10 V Stand-off Voltage, Uni-Directional, -55 to 155 degC, 2-pin DO-214AC, Pb-Free, Tape and Reel | D5 | CMP-0548-00238-2 | Up to date | 1 | Vishay Semiconductors | SMAJ10A-E3/61 | Volume Production | Digikey | SMAJ10A-E3/61GICT-ND | 0.49602 | 2.48008
 | ERJ-6GEYJ563V |  | R17 | CMP-2001-00434-1 | Up to date | 1 | Panasonic | ERJ-6GEYJ563V | Volume Production | Digikey | P56KACT-ND | 0.06355 | 0.63552
 | 5414373-1 | CONN BNC JACK R/A 50 OHM PCB | J4 | CMP-03357-000008-1 | Up to date | 1 | TE Connectivity | 5414373-1 | Volume Production | Digikey | A32274-ND | 7.81226 | 39.06129
 | WP7113SURC | WP7113SURC Red 5 mm 20 º Water Clear 3800 mcd 1.9 V Solid State LED Lamp - T-1 3/4 | D7, D8, D9 | CMP-00682-00869413-1 | Up to date | 3 | Kingbright | WP7113SURC | Volume Production | Digikey | 754-1279-ND | 0.40146 | 6.02195
 | SF-1206S050-2 | FUSE BOARD MNT 500MA 63VDC 1206 | F1 | CMP-07399-000002-1 | Up to date | 1 | Bourns | SF-1206S050-2 | Volume Production | Digikey | SF-1206S050-2CT-ND | 0.78123 | 3.90613
 | 2-1825910-7 | SWITCH TACTILE SPST-NO 0.05A 24V | SW2, SW3, SW4 | CMP-03402-000004-1 | Up to date | 3 | TE Connectivity | 2-1825910-7 | Volume Production | Digikey | 450-1642-ND | 0.19531 | 2.9296
 | B2B-XH-AM(LF)(SN) | CONN HEADER VERT 2POS 2.5MM | J8 | CMP-17439-000037-1 | Up to date | 1 | JST | B2B-XH-AM(LF)(SN) | Unknown

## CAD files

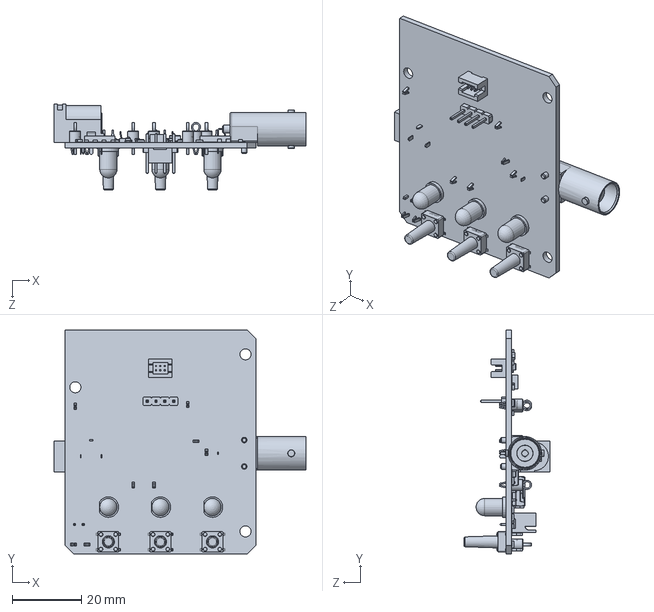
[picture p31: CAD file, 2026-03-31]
CAD/Components/hi.SLDPRT
72.6 x 64.5 x 24.7 mm

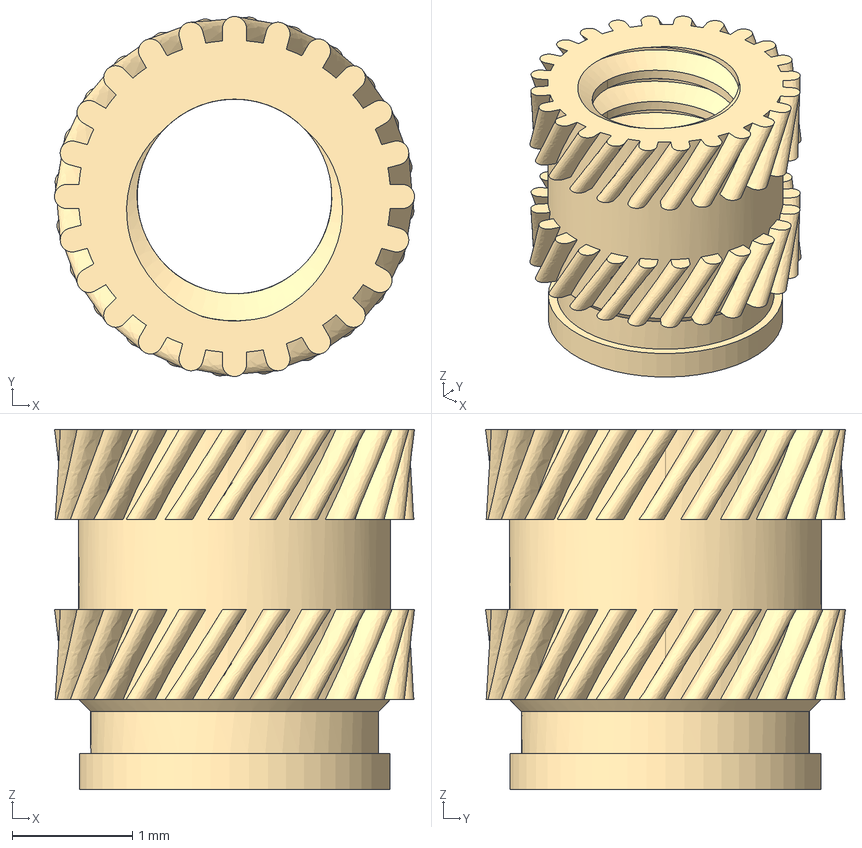
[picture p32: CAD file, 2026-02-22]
CAD/Hardware/Heat Set Insert - M2 3mm x 3mm (ODxL) v3.step
3.00 x 3.00 x 3.00 mm

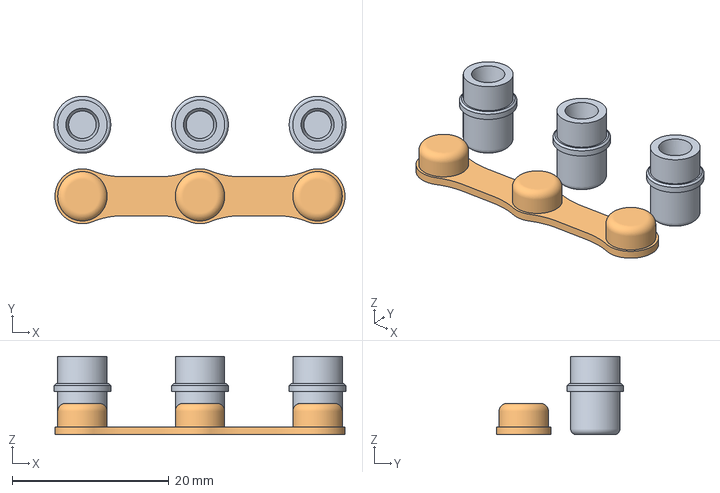
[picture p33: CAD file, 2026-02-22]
CAD/Print_Exports/buttoncaps.3mf
37.2 x 16.2 x 10.0 mm
buttoncaps.STEP
diffuser.STEP

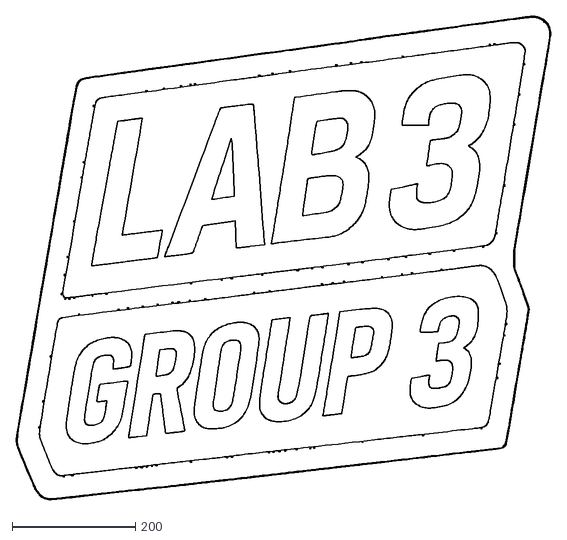
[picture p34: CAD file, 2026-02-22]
Documentation/Branding/junlogol-ol.dxf
868.1 x 785.4

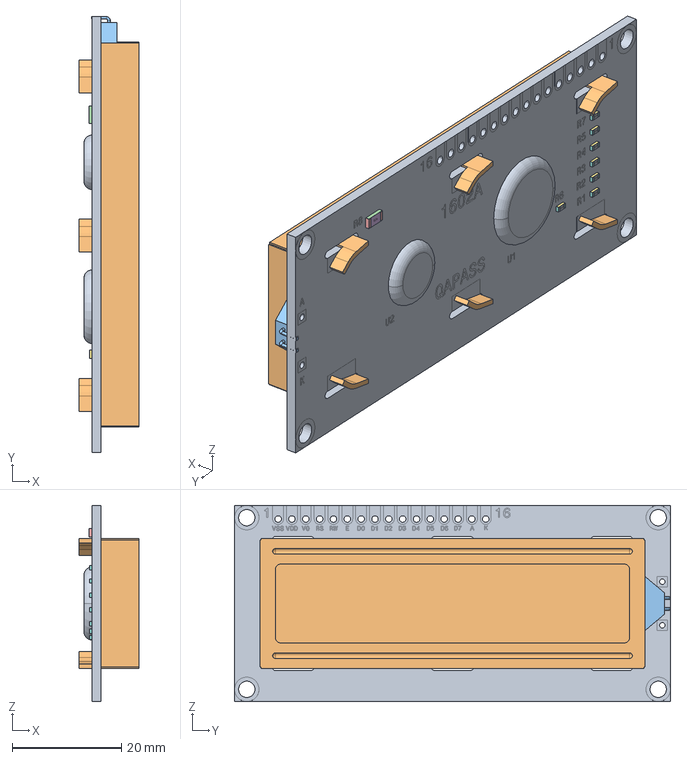
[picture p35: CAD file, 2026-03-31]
Electronics/Reference_Models/MODULO_DISPLAY_LCD1602.stp
11.0 x 80.0 x 36.0 mm

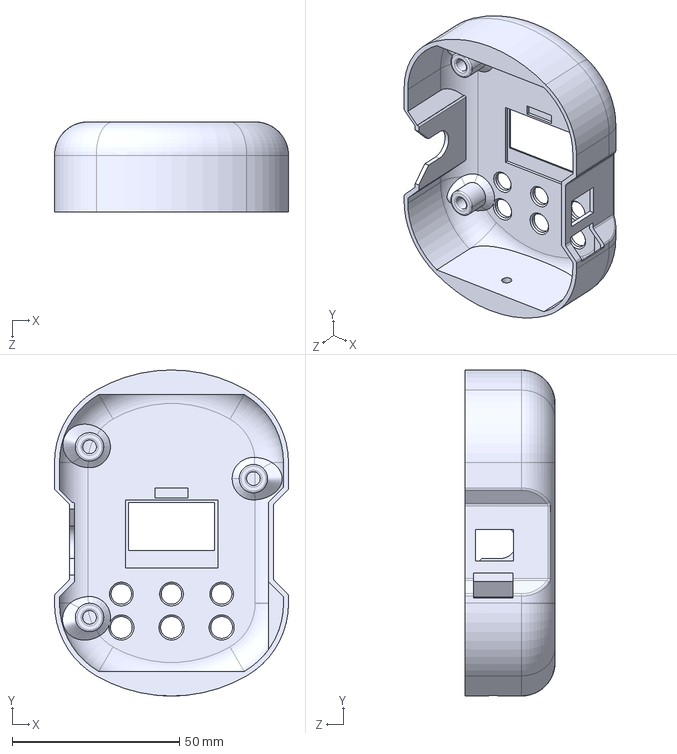
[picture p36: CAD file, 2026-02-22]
CAD/Components/shellfront.STEP
70.0 x 97.5 x 27.0 mm

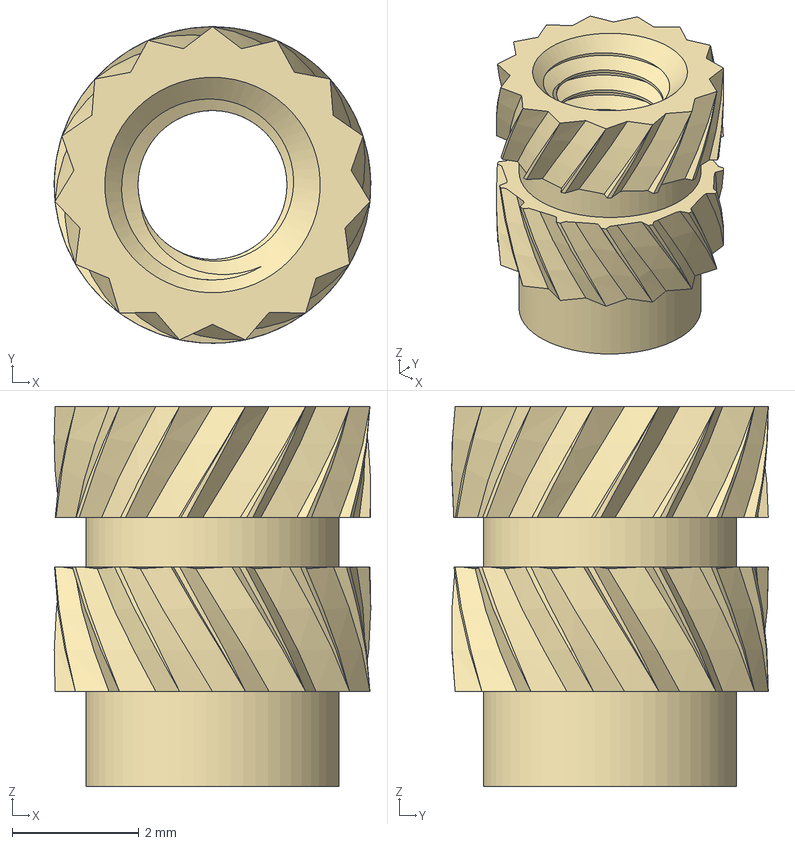
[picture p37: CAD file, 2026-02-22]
CAD/Hardware/Insert M3 D5 L5mm.stp
5.00 x 5.00 x 6.00 mm

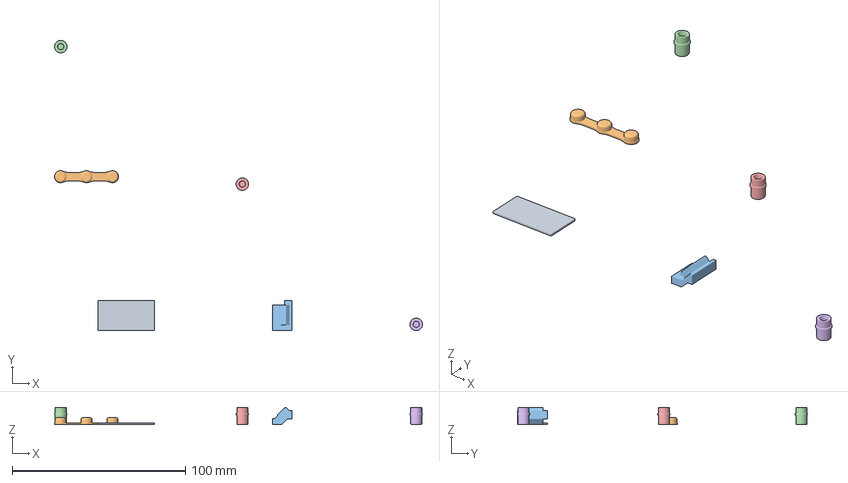
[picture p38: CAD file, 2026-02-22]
CAD/Print_Exports/buttoncap.3mf
212.6 x 167.7 x 10.0 mm
clear.STEP
diffuser.STEP
switchcover.STEP
buttoncap.STEP x 3

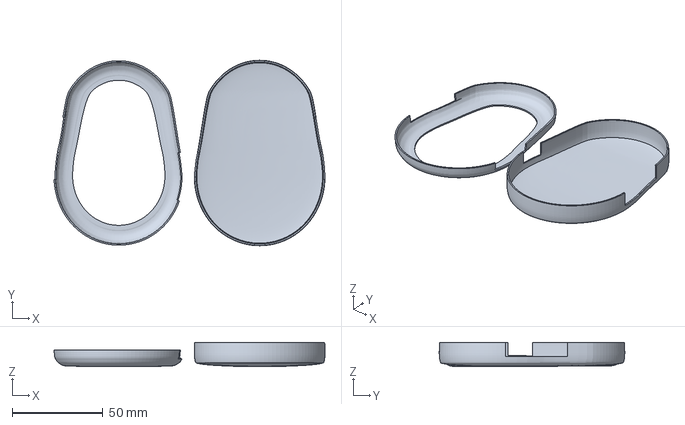
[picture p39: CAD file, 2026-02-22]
Electronics/Reference_Models/PBC2Asave1.3mf
149.2 x 102.2 x 13.5 mm

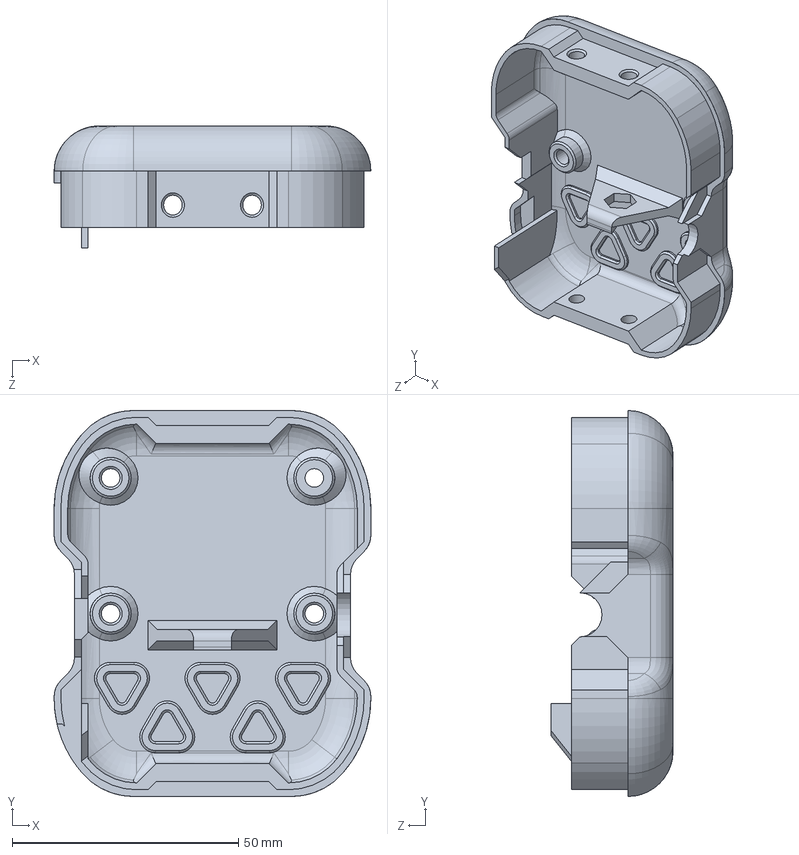
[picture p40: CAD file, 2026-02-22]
CAD/Components/shell6.SLDPRT
70.0 x 85.3 x 27.0 mm

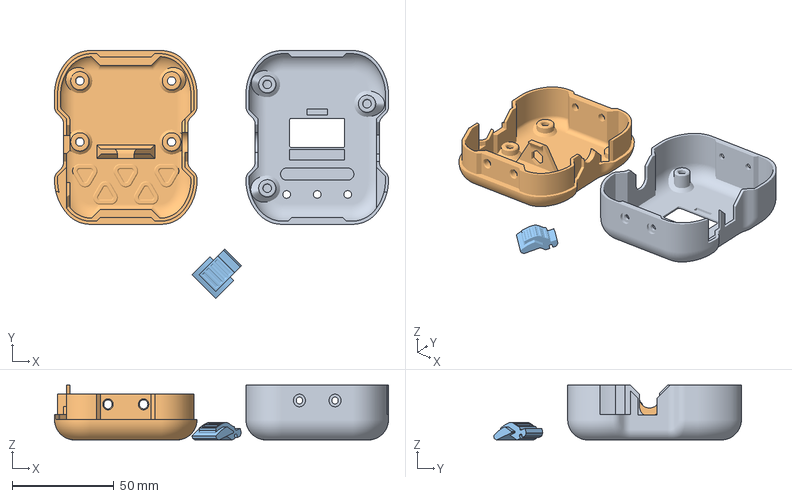
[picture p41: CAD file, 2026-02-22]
CAD/Print_Exports/shellback7.3mf
164.0 x 121.7 x 27.0 mm
shellfront7.STEP
shellback7.STEP
switchcover2.STEP

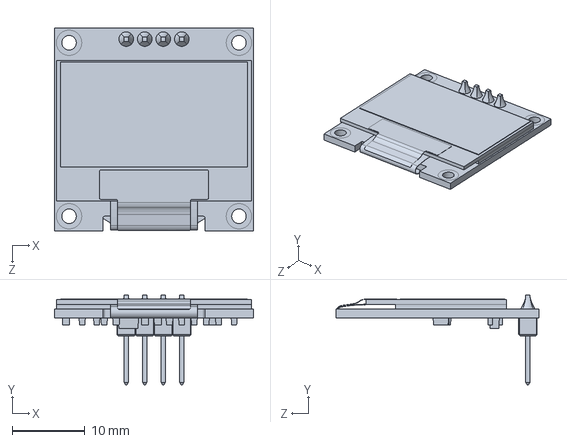
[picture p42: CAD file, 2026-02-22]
Electronics/Reference_Models/OLED TFT 0.96 inch 64x128 monochrome.SLDPRT
27.3 x 12.3 x 27.8 mm

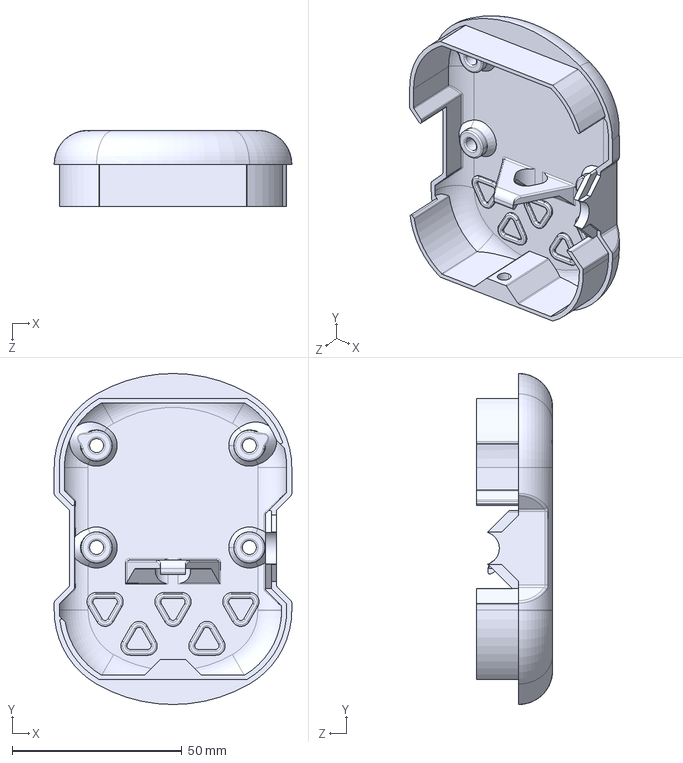
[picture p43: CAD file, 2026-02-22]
CAD/Components/shellback.STEP
70.0 x 97.5 x 22.5 mm

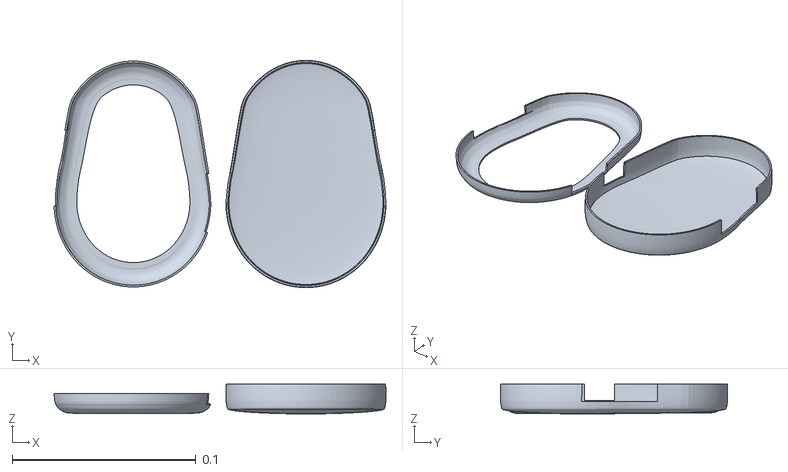
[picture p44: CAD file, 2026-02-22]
CAD/Print_Exports/encolsureproto1(1).stl
0.181 x 0.124 x 0.0163

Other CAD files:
CAD/Assemblies/electronics package.SLDASM
CAD/Assemblies/pcb bruh 5.SLDASM
Electronics/Reference_Models/SSD1306_OLED_Display(128x64).step
CAD/Components/shellback7.STEP
CAD/Components/9V_BatteryAdaptor.SLDPRT
CAD/Components/9V_BatteryAdaptor.step
CAD/Components/Battery_9V.SLDPRT
CAD/Components/buttoncap.STEP
CAD/Components/buttoncaps.STEP
CAD/Components/clear.STEP
CAD/Components/clip2.SLDPRT
CAD/Components/clip2.STEP
CAD/Components/clip3.STEP
CAD/Components/diffuser.STEP
CAD/Components/oledspacer.STEP
CAD/Components/shell7.STEP
CAD/Components/shellback6.STEP
CAD/Components/shellfront6.STEP
CAD/Components/shellfront7.STEP
CAD/Components/switchcover.STEP
CAD/Components/switchcover2.5.SLDPRT
CAD/Components/switchcover2.5.STEP
CAD/Components/switchcover2.SLDPRT
CAD/Components/switchcover2.STEP
CAD/Print_Exports/clip2.3mf
CAD/Print_Exports/shellback.3mf
CAD/Print_Exports/switchcover2.3mf
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

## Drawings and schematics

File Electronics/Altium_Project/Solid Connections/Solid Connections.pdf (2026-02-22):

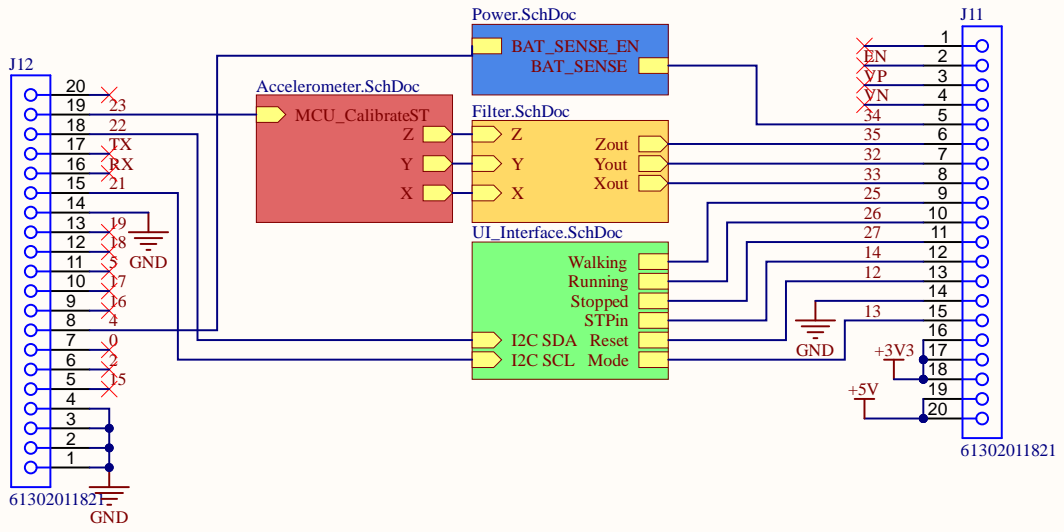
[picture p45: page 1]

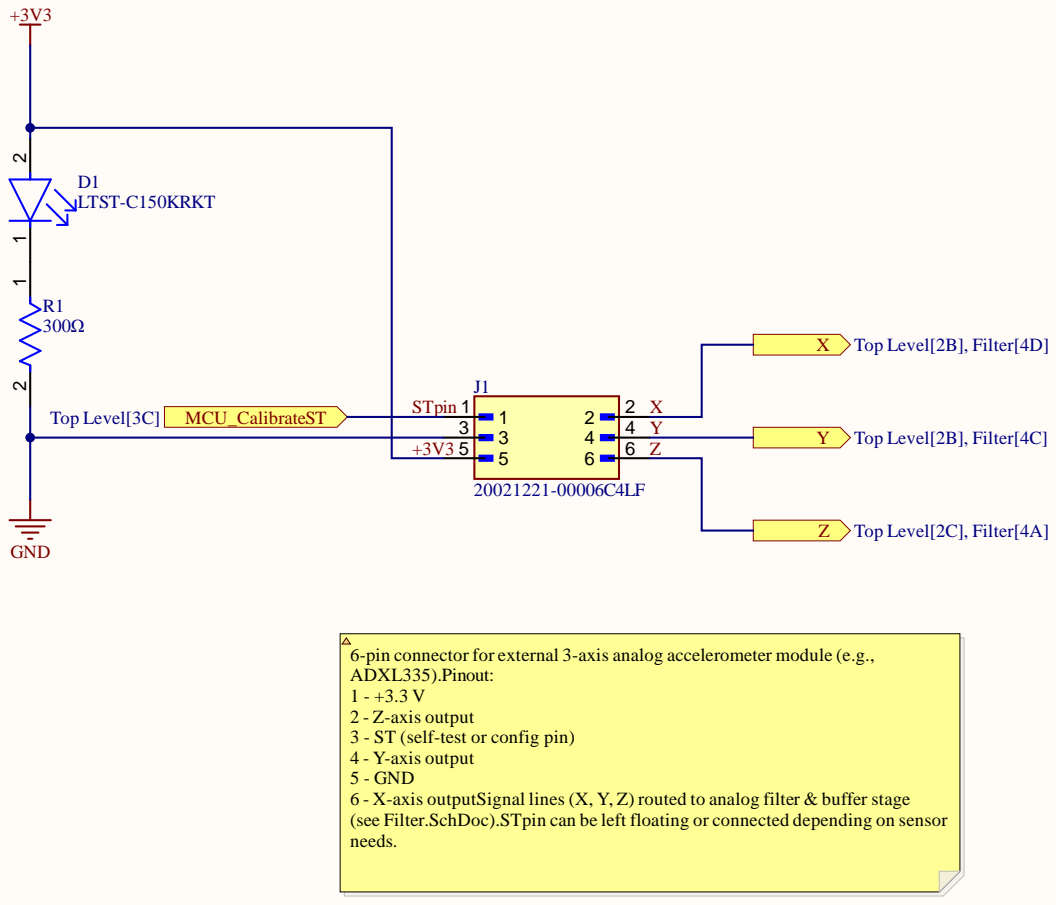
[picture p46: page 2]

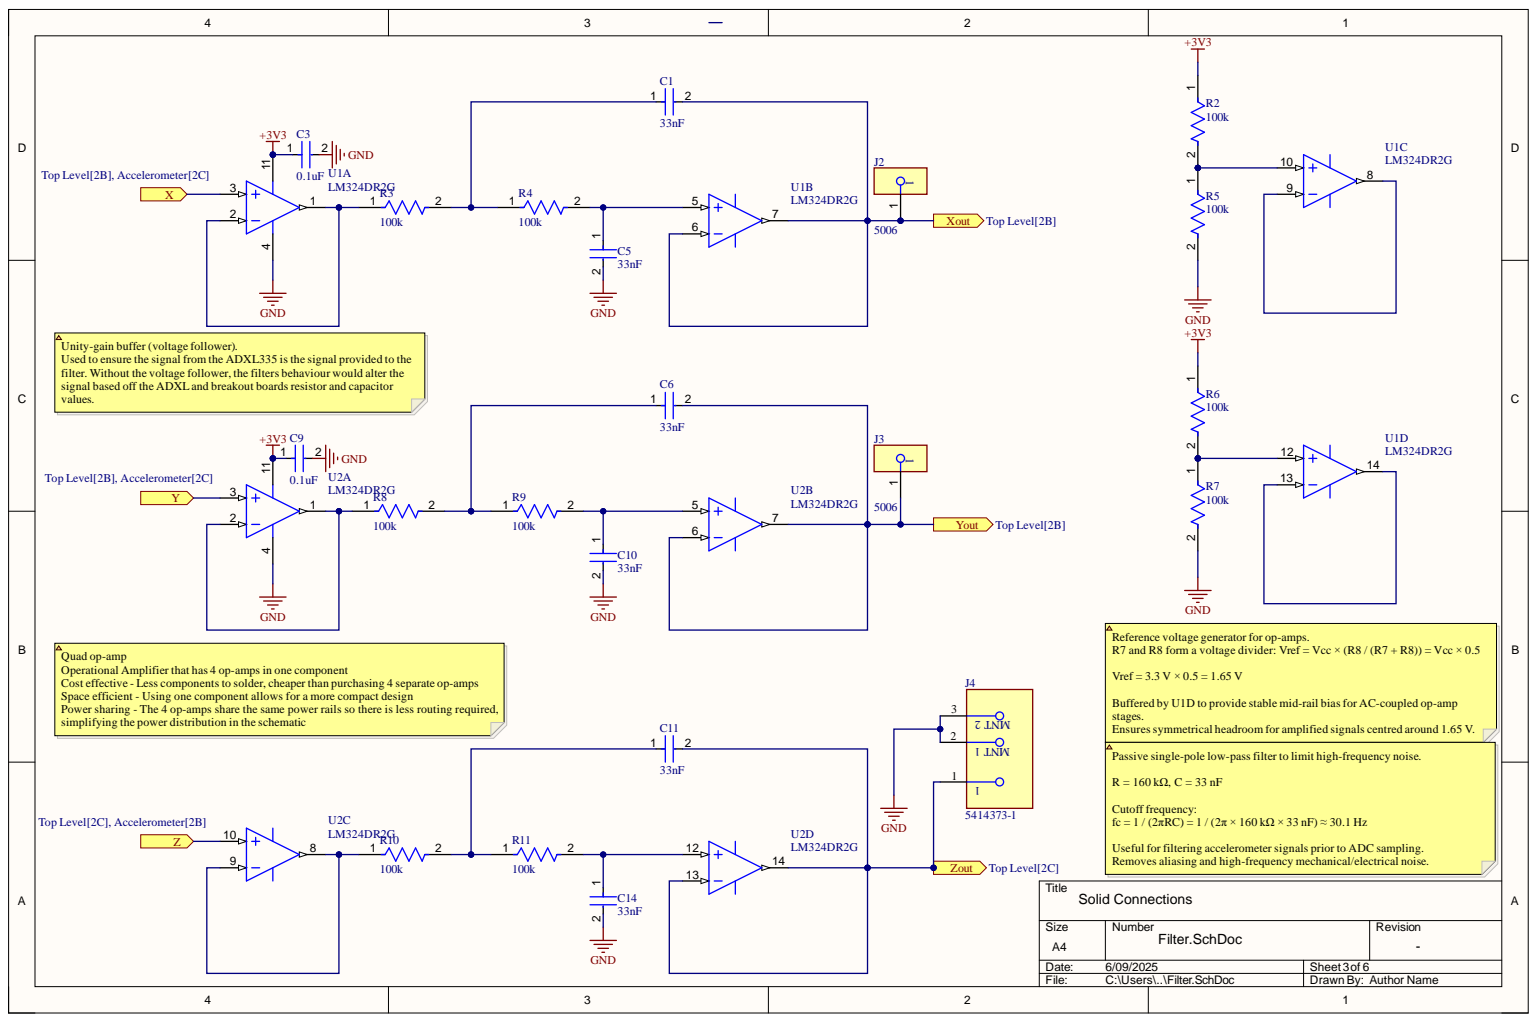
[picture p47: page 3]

Unity-gain buffer (voltage follower).
Used to ensure the signal from the ADXL335 is the signal provided to the
filter. Without the voltage follower, the filters behaviour would alter the
signal based off the ADXLand breakout boards resistor and capacitor
values.

Reference voltage generator for op-amps.
R7 and R8 form a voltage divider: Vref = Vcc × (R8 / (R7 + R8)) = Vcc × 0.5

Quad op-amp
Operational Amplifier that has 4 op-amps in one component
Cost effective - Less components to solder, cheaper than purchasing 4 separate op-amps
Space efficient - Using one component allows for a more compact design
Power sharing - The 4 op-amps share the same power rails so there is less routing required,
simplifying the power distribution in the schematic

Buffered by U1D to provide stable mid-rail bias for AC-coupled op-amp
stages.
Ensuressymmetrical headroom for amplified signals centred around 1.65 V.

Passive single-pole low-pass filter to limit high-frequency noise.

Cutoff frequency:
fc = 1 / (2πRC) = 1 / (2π × 160 kΩ × 33 nF) ≈ 30.1 Hz

Useful for filtering accelerometer signals prior to ADC sampling.
Removes aliasing and high-frequency mechanical/electrical noise.

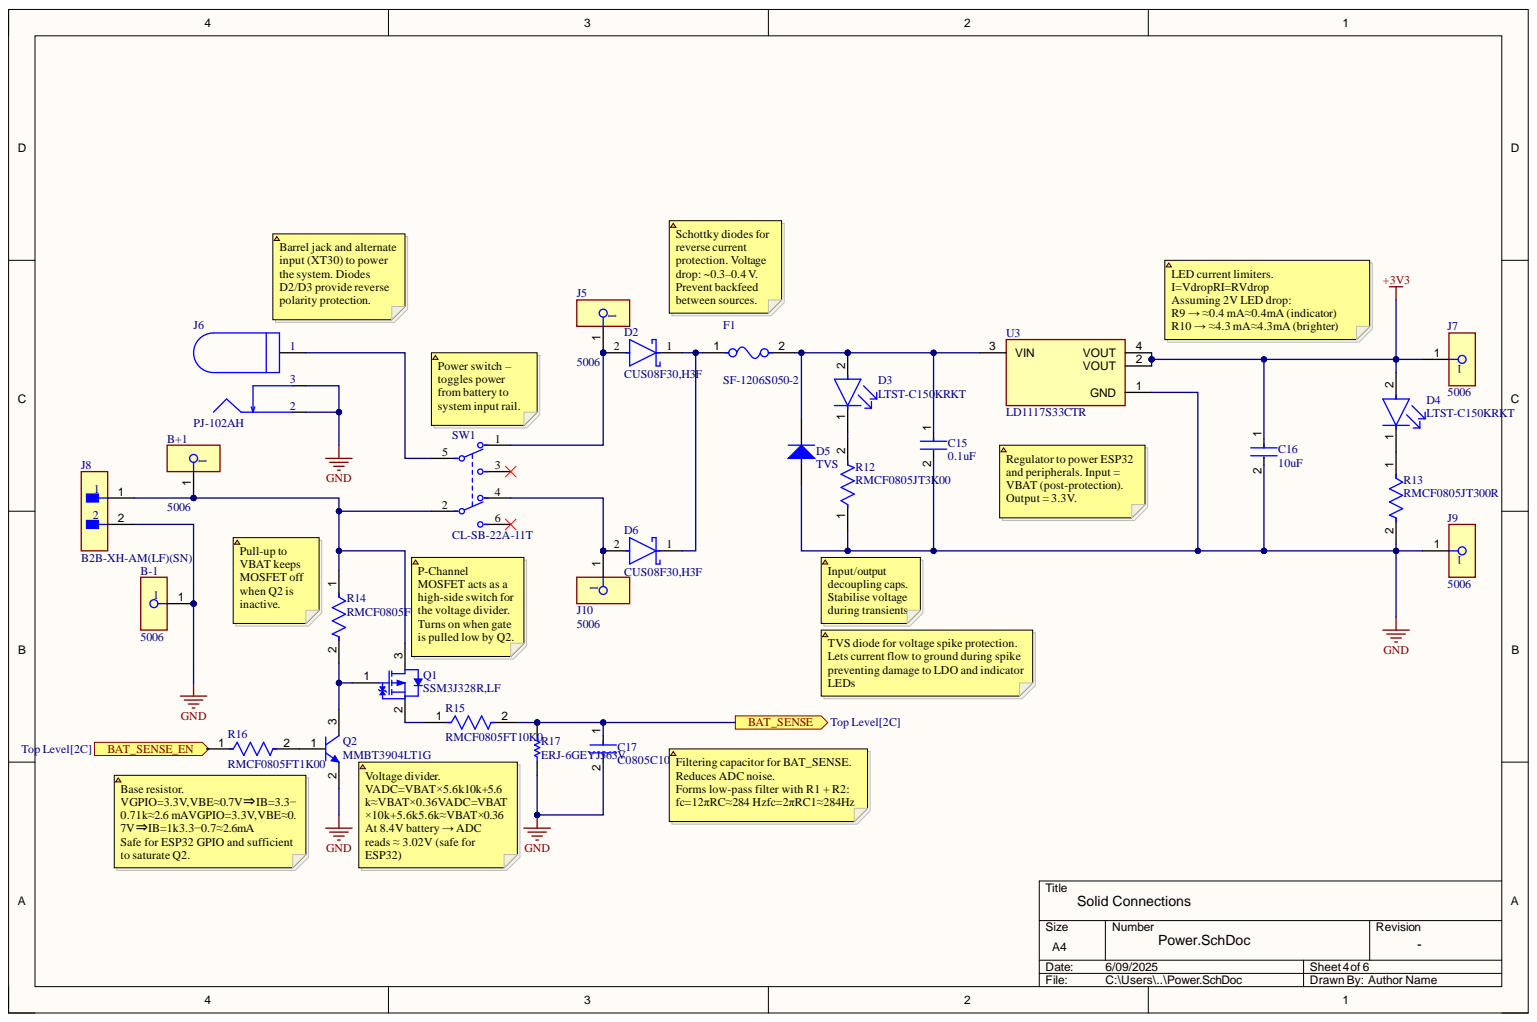
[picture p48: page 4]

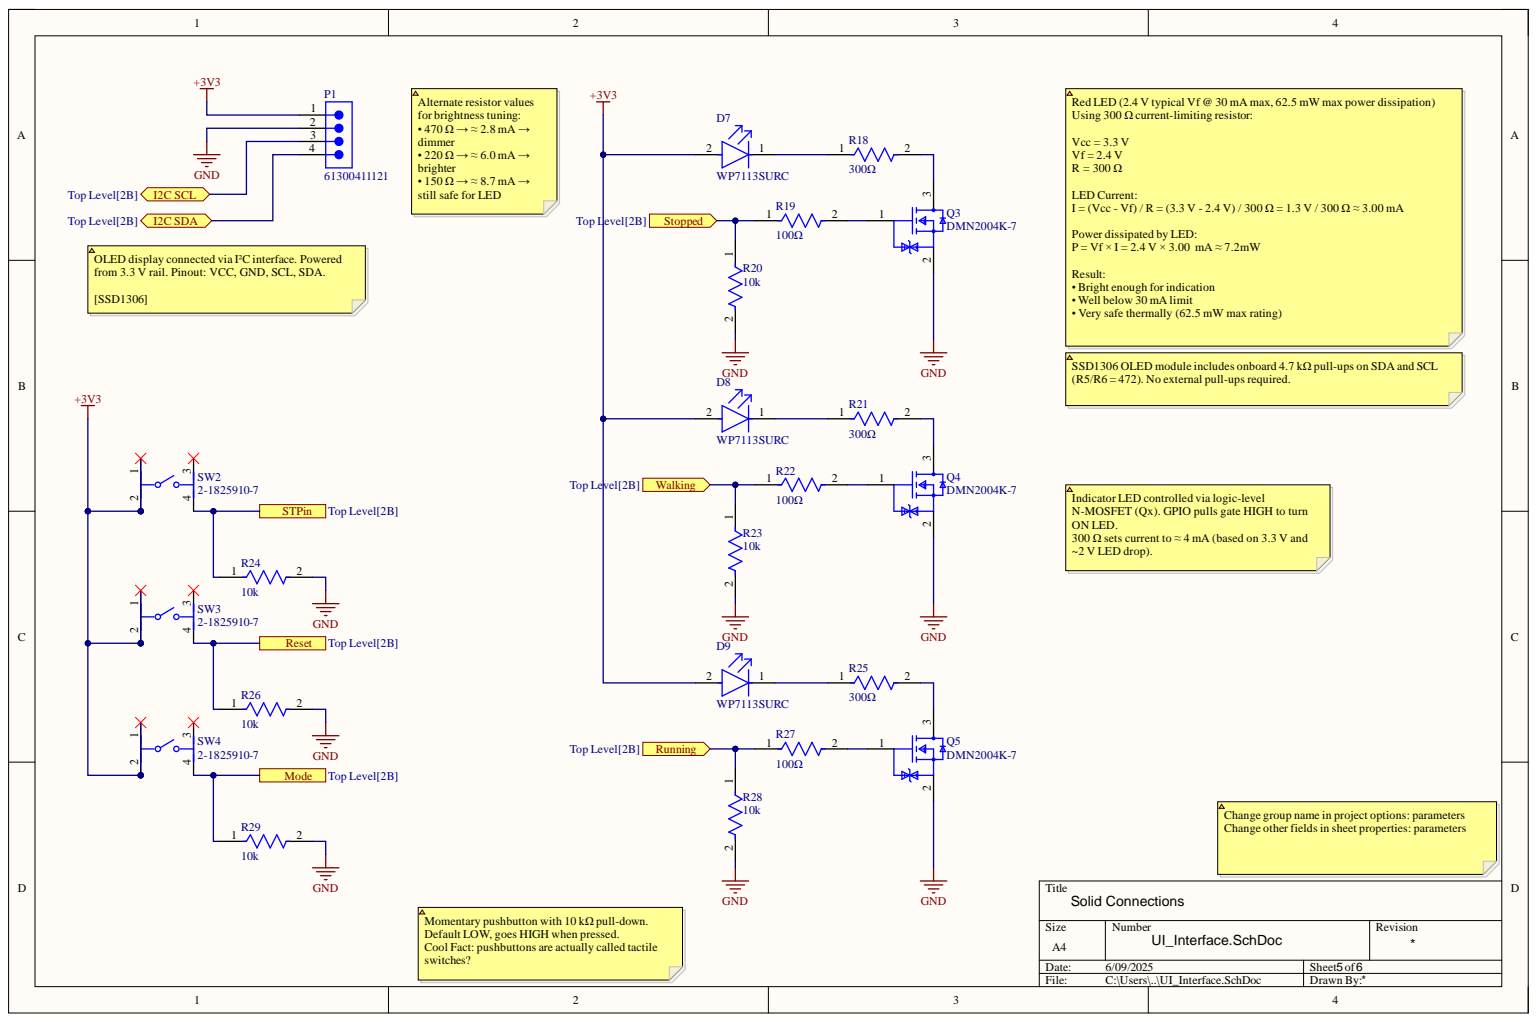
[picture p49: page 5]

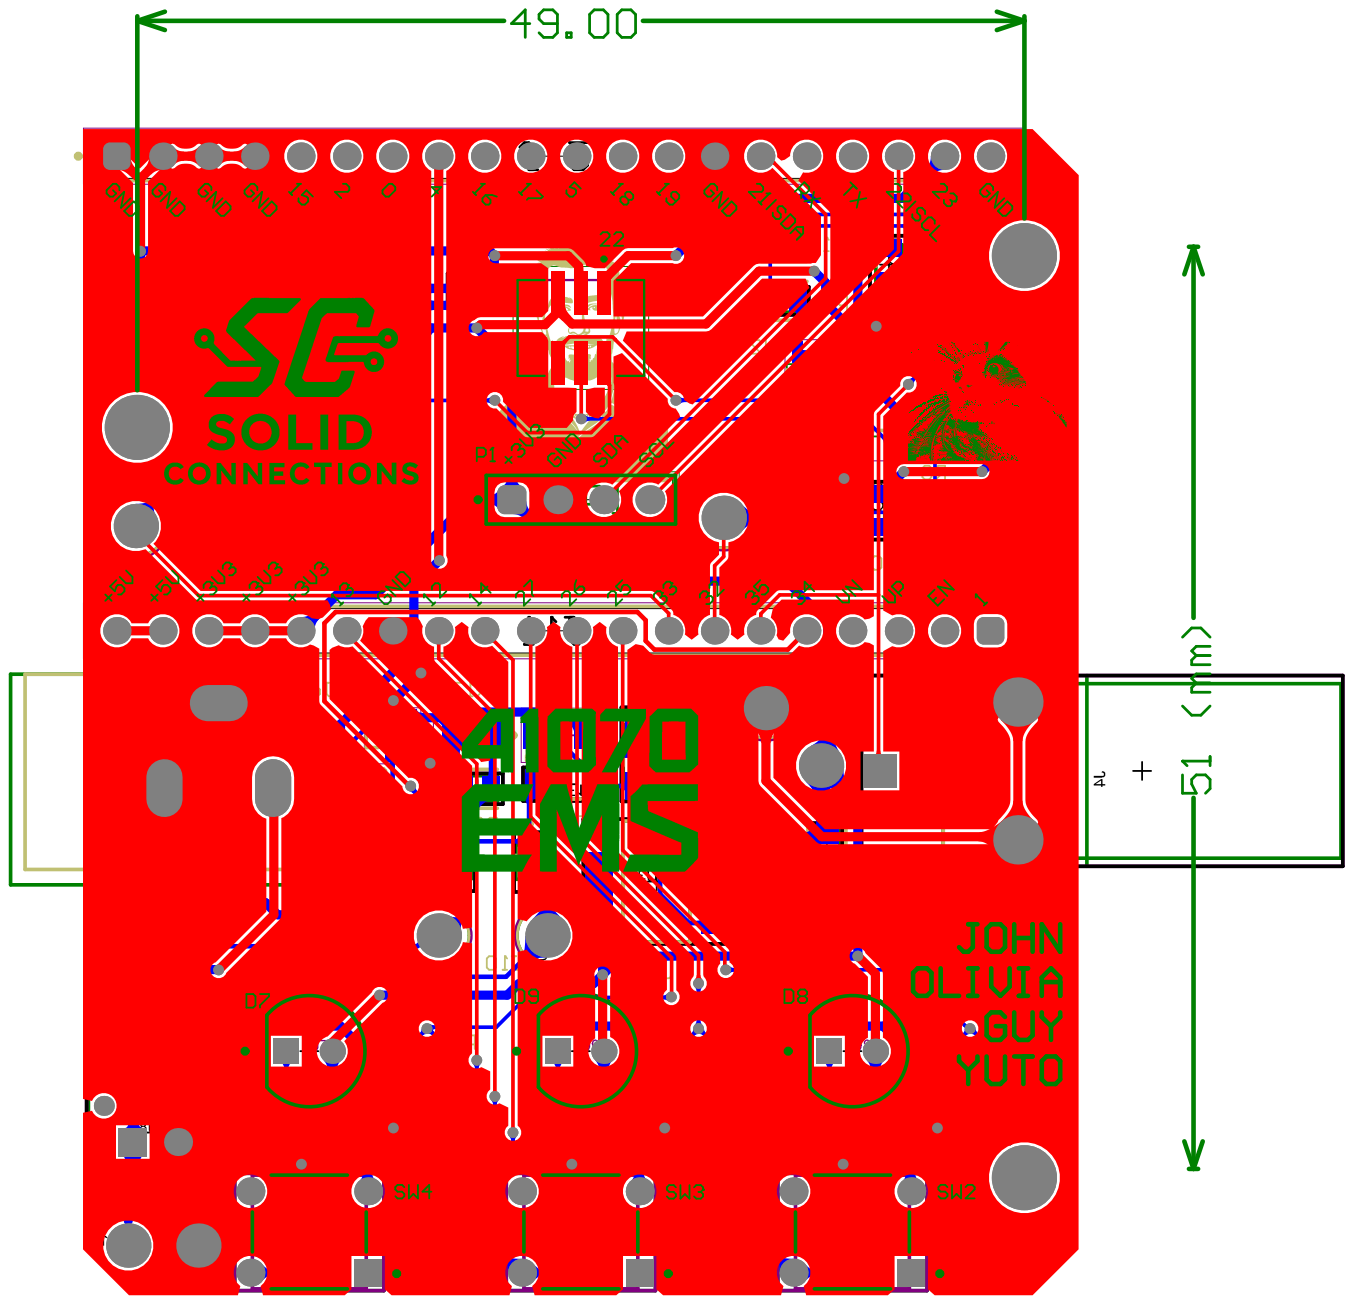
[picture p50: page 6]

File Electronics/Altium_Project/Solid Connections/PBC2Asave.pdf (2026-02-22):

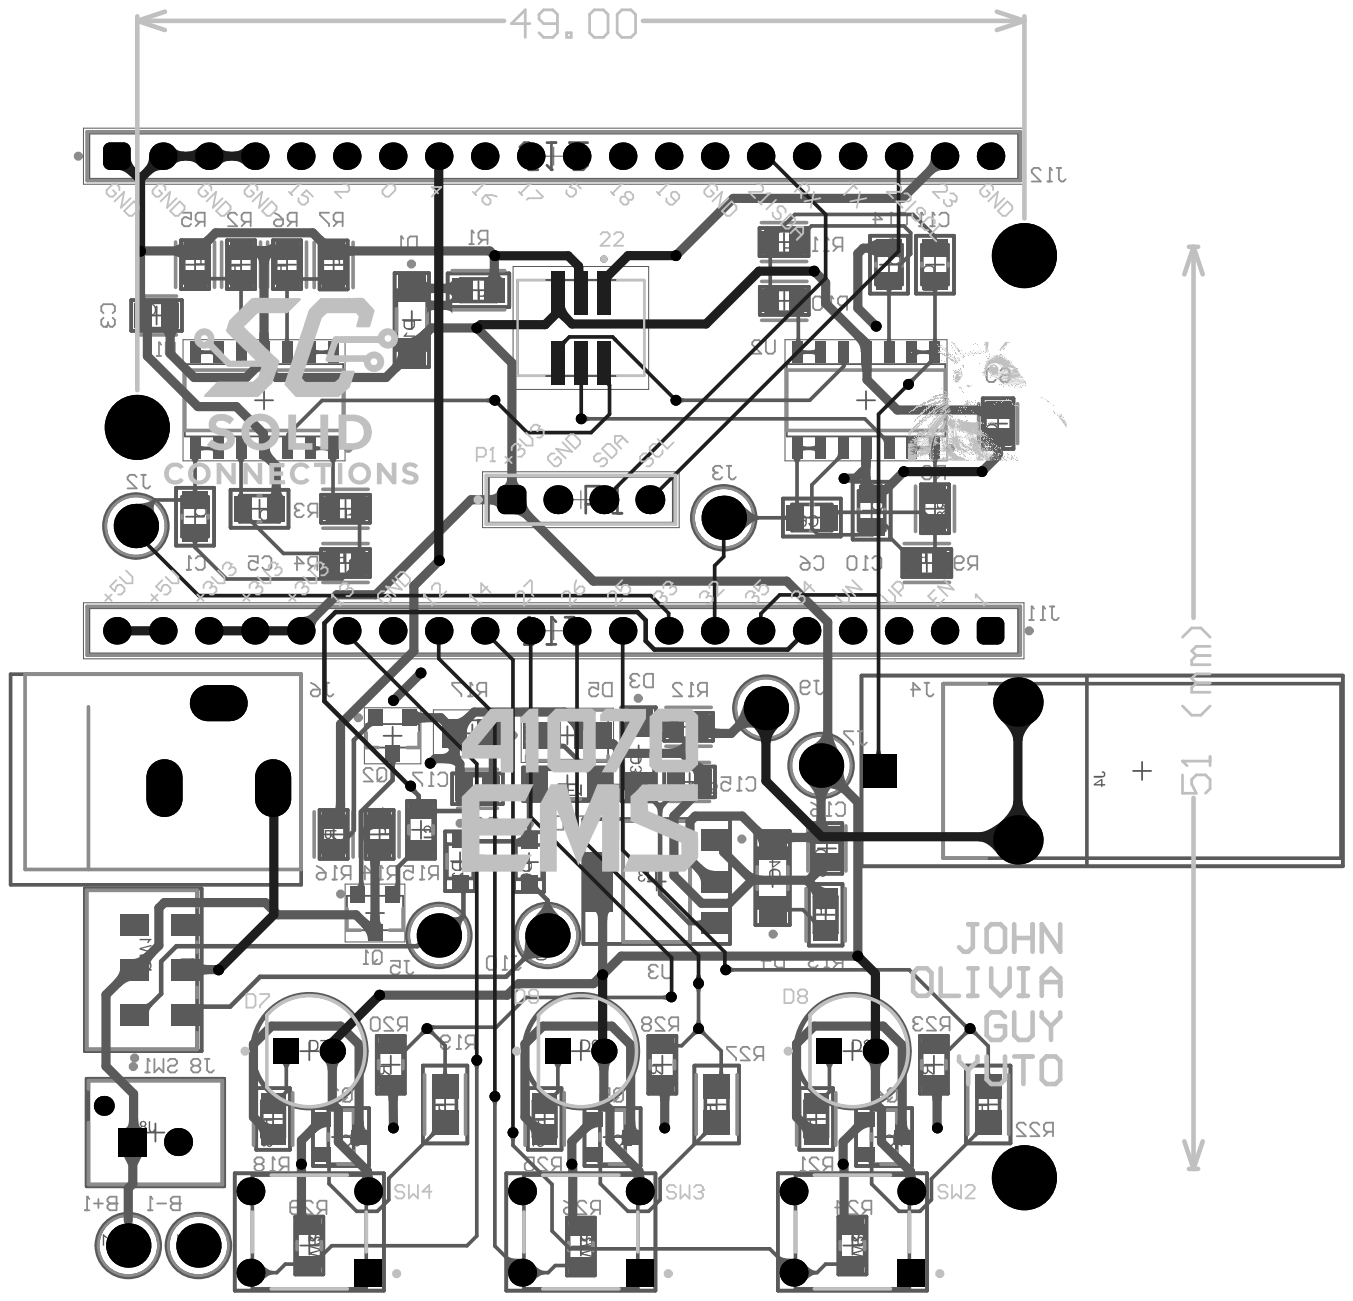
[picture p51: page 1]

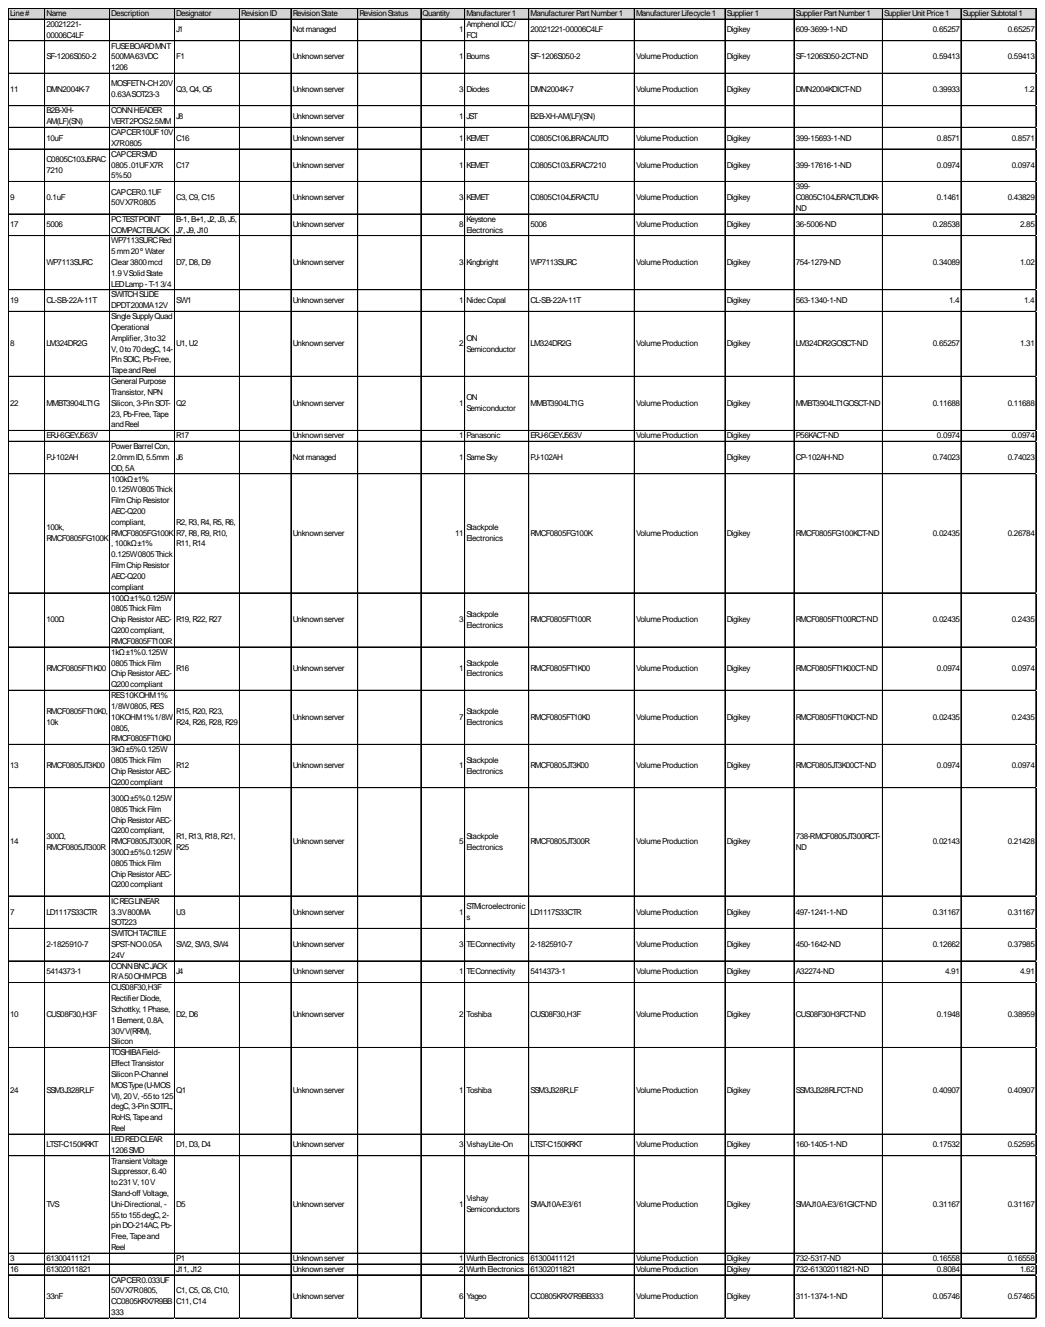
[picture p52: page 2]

Line# | Name | Description | Designator | RevisionID | RevisionState | RevisionStatus | Quantity | Manufacturer 1 | Manufacturer Part Number 1 | Manufacturer Lifecycle 1 | Supplier 1 | Supplier Part Number 1 | Supplier Unit Price 1 | Supplier Subtotal 1

20021221-00006C4LF | | J1 | | Not managed | | | 1 Amphenol ICC/ FCI | 20021221-00006C4LF | | Digikey | 609-3699-1-ND | 0.65257 | 0.65257

SF-1206S050-2 | FUSEBOARDMNT 500MA63VDC 1206 | F1 | | Unknownserver | | | 1 Bourns | SF-1206S050-2 | VolumeProduction | Digikey | SF-1206S050-2CT-ND | 0.59413 | 0.59413

11 | DMN2004K-7 | MOSFETN-CH20V 0.63ASOT23-3 | Q3, Q4, Q5 | | Unknownserver | | | 3 Diodes | DMN2004K-7 | VolumeProduction | Digikey | DMN2004KDICT-ND | 0.39933 | 1.2

B2B-XH-AM(LF)(SN) | CONNHEADER VERT2POS2.5MM | J8 | | Unknownserver | | | 1 JST | B2B-XH-AM(LF)(SN)

10uF | CAPCER10UF10V X7R0805 | C16 | | Unknownserver | | | 1 KEMET | C0805C106J8RACAUTO | VolumeProduction | Digikey | 399-15693-1-ND | 0.8571 | 0.8571

C0805C103J5RAC 7210 | CAPCERSMD 0805.01UFX7R 5%50 | C17 | | Unknownserver | | | 1 KEMET | C0805C103J5RAC7210 | VolumeProduction | Digikey | 399-17616-1-ND | 0.0974 | 0.0974

9 | 0.1uF | CAPCER0.1UF 50VX7R0805 | C3, C9, C15 | | Unknownserver | | | 3 KEMET | C0805C104J5RACTU | VolumeProduction | Digikey | 399-C0805C104J5RACTUDKR-ND | 0.1461 | 0.43829

17 | 5006 | PCTESTPOINT COMPACTBLACK | B-1, B+1, J2, J3, J5, J7, J9, J10 | | Unknownserver | | | 8 Keystone Electronics | 5006 | VolumeProduction | Digikey | 36-5006-ND | 0.28538 | 2.85

WP7113SURC | WP7113SURCRed 5mm20º Water Clear 3800mcd 1.9VSolidState LEDLamp- T-13/4 | D7, D8, D9 | | Unknownserver | | | 3 Kingbright | WP7113SURC | VolumeProduction | Digikey | 754-1279-ND | 0.34089 | 1.02

19 | CL-SB-22A-11T | SWITCHSLIDE DPDT200MA12V | SW1 | | Unknownserver | | | 1 Nidec Copal | CL-SB-22A-11T | | Digikey | 563-1340-1-ND | 1.4 | 1.4

8 | LM324DR2G | SingleSupplyQuad Operational Amplifier, 3to32 V, 0to70degC, 14-PinSOIC, Pb-Free, TapeandReel | U1, U2 | | Unknownserver | | | 2 ON Semiconductor | LM324DR2G | VolumeProduction | Digikey | LM324DR2GOSCT-ND | 0.65257 | 1.31

22 | MMBT3904LT1G | General Purpose Transistor, NPN Silicon, 3-PinSOT-23, Pb-Free, Tape andReel | Q2 | | Unknownserver | | | 1 ON Semiconductor | MMBT3904LT1G | VolumeProduction | Digikey | MMBT3904LT1GOSCT-ND | 0.11688 | 0.11688

ERJ-6GEYJ563V | | R17 | | Unknownserver | | | 1 Panasonic | ERJ-6GEYJ563V | VolumeProduction | Digikey | P56KACT-ND | 0.0974 | 0.0974
PJ-102AH | Power Barrel Con, 2.0mmID, 5.5mm OD, 5A | J6 | | Not managed | | | 1 SameSky | PJ-102AH | | Digikey | CP-102AH-ND | 0.74023 | 0.74023

100k, RMCF0805FG100K | 100kΩ±1% 0.125W0805Thick Film ChipResistor AEC-Q200 compliant, RMCF0805FG100K , 100kΩ±1% 0.125W0805Thick Film ChipResistor AEC-Q200 compliant | R2, R3, R4, R5, R6, R7, R8, R9, R10, R11, R14 | | Unknownserver | | 11 | Stackpole Electronics | RMCF0805FG100K | VolumeProduction | Digikey | RMCF0805FG100KCT-ND | 0.02435 | 0.26784

100Ω | 100Ω±1%0.125W 0805ThickFilm ChipResistor AEC-Q200compliant, RMCF0805FT100R | R19, R22, R27 | | Unknownserver | | | 3 Stackpole Electronics | RMCF0805FT100R | VolumeProduction | Digikey | RMCF0805FT100RCT-ND | 0.02435 | 0.2435

RMCF0805FT1K00 | 1kΩ±1%0.125W 0805ThickFilm ChipResistor AEC-Q200compliant | R16 | | Unknownserver | | | 1 Stackpole Electronics | RMCF0805FT1K00 | VolumeProduction | Digikey | RMCF0805FT1K00CT-ND | 0.0974 | 0.0974

RMCF0805FT10K0, 10k | RES10KOHM1% 1/8W0805, RES 10KOHM1%1/8W 0805, RMCF0805FT10K0 | R15, R20, R23, R24, R26, R28, R29 | | Unknownserver | | | 7 Stackpole Electronics | RMCF0805FT10K0 | VolumeProduction | Digikey | RMCF0805FT10K0CT-ND | 0.02435 | 0.2435

13 | RMCF0805JT3K00 | 3kΩ±5%0.125W 0805ThickFilm ChipResistor AEC-Q200compliant | R12 | | Unknownserver | | | 1 Stackpole Electronics | RMCF0805JT3K00 | VolumeProduction | Digikey | RMCF0805JT3K00CT-ND | 0.0974 | 0.0974

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

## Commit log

2026-02-22 Initial dump
    all the work on my machine is now here
    [9V_BatteryAdaptor.SLDPRT, 9V_BatteryAdaptor.step, BOM_[No Variations].csv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]
2026-02-22 secret files
    [61300411121_CMP-1502-01064-3.x_t, 61302011821_CMP-1502-01348-3.x_t, AMPHENOL_20021221-00006C4LF_20021221-00006C4LF.x_t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]
2026-03-31 chore(repo): reorganize project layout and normalize documentation assets
    [61300411121_CMP-1502-01064-3.x_t, 61302011821_CMP-1502-01348-3.x_t, 9V_BatteryAdaptor.SLDPRT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]
